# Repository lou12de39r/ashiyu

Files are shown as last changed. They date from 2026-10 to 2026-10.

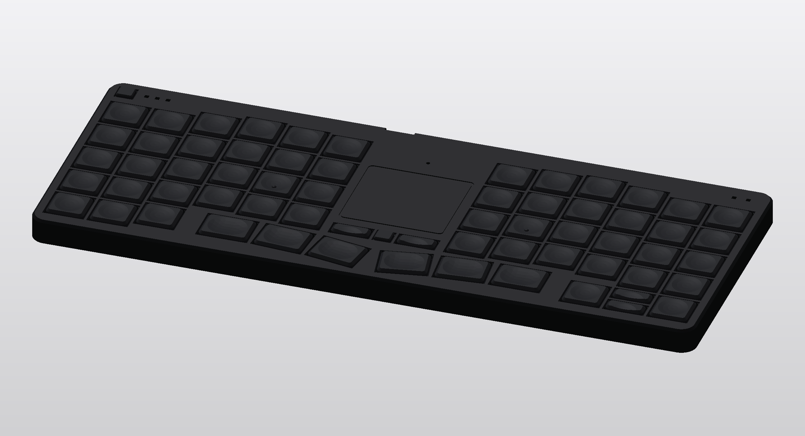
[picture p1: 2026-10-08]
docs/case_black_black_caps.png

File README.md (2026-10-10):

# Ashiyu（足湯）— tomtho-slim mk2: layout v20 and board plan

**Ashiyu（足湯）** — tomtho-slim mk2 の愛称。Designed by tommys079.
Inspired by [ClickBoard](https://salicylic-acid3.hatenablog.com/) by Salicylic_acid3（自作キーボード温泉街）. Keycap models are derived from ACC Keycaps (CC BY-NC 4.0).

This repository holds the frozen layout and the board plan for the second keyboard: roBa-style column stagger, centre trackpad, thin case.

| File | Contents |
|---|---|
| `layout_v20.py` | Script that draws the layout (`roba_ortho_v20.png`) |
| `layout_v20.json` | Fixed coordinates of every key, the trackpad and the LEDs (mm; origin is the rear-left corner of the outline, +y towards the user) |
| `freeze.py` | Regenerates the JSON above from `layout_v20.py` |
| `ORDER.md` | 発注手順: JLCPCB の基板と実装, JLC3DP のケース |
| `case/` | ケース: 上フレームと底板 (CadQuery)。出力は `case-results` ブランチ |
| `layout_v20_print_A4.pdf` / `print11.py` | 1:1 print sheet (A4 landscape). Print at **actual size / 100%** and check the 100 mm bar with a ruler |

## Settled specification

### Layout
- **Keys:** 66 total (v22: lower-left Ctrl 1u, Fn / Win 0.5u stacked, Alt 1u, mirroring the arrow cluster).
  - Left block: 6 columns × number row + 3 rows, plus Fn / Ctrl→**Alt** (firmware) / Win.
  - Right block: 6 columns × number row + 3 rows, plus arrows (← ↑↓ →; ↑ and ↓ are stacked 0.5u keys).
  - Thumbs (v21): 3 per side — outer 1u, **middle (Space / Enter) 1.25u**, inner 1u — at 1.1u spacing. Fan is half of roBa's: tilt 0 / 4.5 / 10°, drop 0 / 0.8 / 3.5 mm.
  - Centre: mouse L / R (1u × 0.5u) and M (0.5u × 0.5u), 2.5 mm below the trackpad window (v21).
  - Rear strip, top-left: BT key (0.5u × 0.5u; tap = next profile, 1 s hold = clear and re-pair).
- **Pitch:** 18.5 × 18.0 mm.
- **Column stagger (v21):** 0.75 × roBa's offsets (was 0.5). Relative to the pinky column: ring 5.0, middle 8.3, index 6.6, inner 4.8 mm towards the rear. The trackpad top lines up with the tops of T / Y; the MCU module, USB-C and charger sit in the free area above it (nothing is stacked under the trackpad).
- **Outline:** 277.0 × 107.5 mm.
- **Trackpad:** Azoteq **TPS43-201A-S** module, 43 × 40 mm (window centred in the 51 mm centre gap, top aligned with T / Y). The keys did not move when the pad shrank from 49 × 42.
- **LEDs:**
  - BT1–3, green: light for 3 s on a press; blink while waiting to pair.
  - Power, yellow-green/red bicolour XL-2012SURSYGC (firmware): green for 3 s on power-up and on a profile switch; below 20 % a short red blink every 5 s.
  - Charge, orange: driven directly by the charger STAT pin; lights only while USB is connected.

### Matrix and GPIO (draft)

| Row | Left side (C0–C5) | Right side (C6–C11) |
|---|---|---|
| R0 | ` 1 2 3 4 5 | 6 7 8 9 0 - |
| R1 | Tab Q W E R T | Y U I O P [ |
| R2 | Ctl A S D F G | H J K L ' ] |
| R3 | ⇧ Z X C V B | N M , . / Ent |
| R4 | Fn Alt Win 変換 Space 無変換 | BS Enter Del ← ↑ → |
| R5 | BT L M R ↓ (5 keys) | — |

**Pin budget:**

| Function | Pins |
|---|---|
| Matrix (6 rows + 12 columns) | 18 |
| BT LEDs | 3 |
| Power LED | 2 |
| Trackpad (SDA, SCL, RDY, RST) | 4 |
| **Total** | **27** |

Charger STAT is **not** wired to the MCU: the MCP73831 drives STAT up to VBUS (5 V) when charging is done, which would overdrive an nRF GPIO. Firmware can see USB power from the nRF's own VBUS detection instead.

The MDBT50Q has room to spare. Reset, NFC and crystal pins are avoided.

### Trackpad (decided: Azoteq TPS43-201A-S module)
- **Module:** IQS572, 43 × 40 mm, PCB 1.0 mm, ships with 3M 468 adhesive (0.13 mm) for sticking to the underside of an overlay. 1.65–3.6 V, I²C. Ordering code: hardware rev 2 = **ZIF connector** (J1) on the module.
- **J1 pinout (datasheet table 2.1):** 1 RDY, 2 NRST, 3 GND, 4 VDDHI, 5 SCL, 6 SDA. The main board's J3 uses the same numbering.
- **Mounting:** stuck under the case-top window; its underside parts hang into a 44 × 41 mm cut-out in the main board, so the pad sits flush with the case top.
- **Cable:** 6-pin FFC from the module's ZIF to J3 (HC-FPC-05-10-6RLTAG, 0.5 mm). **Unchecked:** the module ZIF's pitch, position and contact side. Choose cable type A or B so that pin 1 reaches pin 1 (a mirrored cable swaps GND and VDD).
- **Gestures:** XY for up to 5 fingers; the IQS572 does 1- and 2-finger gestures itself (two-finger scroll). Three-finger swipe = app switch, done in the firmware driver from the touch coordinates (hold Alt, Tab / Shift+Tab per 8–10 mm, release Alt on lift).
- **Supply (2026-10-08):** Mouser 0 in stock, 170 due 10/28/2026, $4.57 each.
- **Alternative:** the GR-Trackpad65-derived IQS550 board in `trackpad/` (49 × 43, hand-soldered IC) is kept, but it no longer fits the 44 × 41 cut-out.

## Schematic (mk2-0.1)

- **Files:** `tomtho_mk2.kicad_sch` (KiCad 9). `gen/build_sch.py` regenerates it from `gen/design.py`, which in turn reads `layout_v20.json`. CI ERC: **0 errors, 0 warnings**. The netlist re-extracted from the schematic matches `design.py`.
- **Matrix:** drawn as a wired grid, COL → SW → D → ROW.
- **Charge LED:** red KT-0603R, driven straight from the charger STAT pin.
- **Footprints:** USB-C, bicolour LED and FPC come from the LCSC/EasyEDA data (`gen/lcsc/`). Bicolour LED pins: 1 = R−, 2 = R+, 3 = YG−, 4 = YG+.

## PCB (mk2-0.1)

- **Board:** `tomtho_mk2.kicad_pcb`, 2 layers, 276 × 107 mm.
- **Build pipeline:**
  1. `gen/route.py` writes a Specctra DSN and runs Freerouting. GND is routed as a normal net (a tree), then poured on both layers.
  2. `gen/post.py` adds about 600 GND stitching vias.
  3. `gen/build_pcb.py` writes the board, fills the zones and runs KiCad DRC.
- **Check:** DRC with schematic parity gives **0 violations, 0 unconnected, 0 parity** in both local KiCad 10 and CI KiCad 9.
- **Fab files:** JLC BOM/CPL are in `jlc/`. CI exports the Gerbers and drill files to `ci-results:gerber`.
- **USB-C:** top-mount HRO TYPE-C-31-M-12 (C165948). It sits in the free area, so the mid-mount part is not needed.
- **Trackpad cut-out:** 44 × 41 mm for the TPS43, J3 and the I²C pull-ups to its left.
- **ACC keycaps:** their four corner legs come down to 1.5 mm above the PCB (0.5 mm when pressed). The ↑ / ↓ diodes and J3 were moved clear of these leg zones (r 2 mm at the corners minus 1.7 mm).
- **Case mounting (no screws):** 9 × Tadpole Pin D3.0 holes (H1–H9, NPTH Ø 3.1): 4 rear, 2 front, 3 centre (both sides below the trackpad and between the inner thumbs). The case is screwless (hidden spring clips).
- **References:** reset switch SW101, power switch SW102, Schottky D101 (SW1–SW66 / D1–D66 are the keys).
- **JLC placement (CPL):**
  - `gen/jlcrot.py` lays each LCSC/EasyEDA footprint (the one JLC places at 0°) over ours and works out the rotation offset and origin shift. `jlc/*_CPL.csv` already includes them, in the Gerber coordinates (+Y up, as `kicad-cli pcb export pos`).
  - Verified: with the CPL as written, every LCSC pad lands on our pad (≤ 0.2 mm) for every part, including the tilted thumb keys.
  - Offsets applied: SOT-23 +180°; SOT-23-5 / SOT-23-6 +270°; USB-C origin 1.57 mm; MDBT50Q origin 1.70 mm.
  - Checked by pin function rather than pad number: the KT-0603R LED (LCSC pad 2 = K) and the SKRA / TS-1928-B switches (joined pairs 1-2 / 3-4).
  - Still look at JLC's preview once before paying.
- **Charge current:** R3 = 4.7 kΩ → about 210 mA (0.2–0.5 C for an 800–1000 mAh cell; use ≥ 420 mAh).
- **Before ordering, check:**
  - **MDBT50Q-1MV2 (C5118826) stock: LCSC showed 0 (2026-10-08).** If JLC has none either, use pre-order / global sourcing, or send the modules in yourself.
  - **Battery polarity:** J2 pin 1 = + (VBAT). LiPo leads with JST SH plugs come both ways round; check with a meter before plugging in (reversed = charger and MCU destroyed).
  - Board thickness **1.2 mm** must be chosen in the order form.
  - The routing is automatic and rough in places; it could be tidied by hand.
- **Firmware must:**
  - Set UICR REGOUT0 to 3.0 V. The module runs from VDDH, and the erased default is 1.8 V, at which the LEDs (Vf ≈ 1.9–2.0 V) stay dark.
  - Enable pin reset on P0.18.
  - Drive the LEDs active-low (cathode to GPIO).

## Parts check (2026-10-07, LCSC / JLCPCB pages)

| Part | Result |
|---|---|
| IQS550BLQNR (C5271144) | **Out of stock at LCSC.** The trackpad board cannot be assembled at JLC as planned |
| USB-C TYPE-C 16PIN 2MD(073) (C2765186) | In stock, but right-angle SMD, not mid-mount. Not used |
| **USB-C SHOU HAN TYPE-C 16P CB1.6 073 (C2906290)** | **Use this.** Mid-mount (sinks 1.6 mm), 16-pin, 6.5 mm long, plentiful stock (LCSC). JLC rates assembly difficulty "High". It is made for a 1.6 mm board, so on our 1.2 mm board it sticks out about 0.4 mm below → add a pocket in the case bottom |
| FPC 0.5 mm 6-pin HC-FPC-05-10-6RLTAG (C5213729) | In stock (5k), bottom contact, flip lock |
| Green LED 19-217/GHC (C72043) | Vf 3.3 V: **too high for a 3.0 V VDD**. Needs a yellow-green (≈2.0 V) part instead |
| Red LED KT-0603R (C2286) | Vf 1.8–2.4 V, usable |
| Bicolour LED XINGLIGHT XL-2012SURSYGC (C965847) | **Use this.** 2.0 × 1.2 mm, common anode, red + yellow-green (Vf ≈ 2.4 V at 20 mA; lower at 1–2 mA, so it works from 3.0 V). In stock (20k) |
| IQS550-BL-QNR elsewhere | Octopart lists it only at non-authorised resellers (about 1.1k and 32k pcs, $1.7–3.0). Stock at Mouser / DigiKey could not be read (unconfirmed) |

## Verify before ordering (in priority order)
1. **TPS43 connector:** get the drawing (or measure a module): the ZIF's pitch, position and contact side, and the FFC length and type. Pin 1 must reach pin 1.
2. **ZMK driver for the IQS572 / TPS43:** QMK has an Azoteq IQS5xx driver. For ZMK only community drivers exist (unchecked).
3. **Height:** check that the parts in the free area (module about 2.2 mm, USB-C) fit under the case top, and that the TPS43's underside parts clear the cut-out and the case floor.
4. **Keycaps:** fit of the Acid Caps on the tilted thumb keys, checked by laying out the 3D data.
5. **0.5u × 0.5u caps (BT, M):** these are not sold, so they must be made. Print a test piece first.

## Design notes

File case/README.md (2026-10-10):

# Ashiyu (tomtho-slim mk2) case: top frame + bottom plate

The case is generated in CadQuery by CI (`.github/workflows/case.yml`). Results, including STEP/STL files, section views and interference checks, go to the **`case-results`** branch.

## Files

| File | Role |
|---|---|
| `export_inputs.py` | Run locally with KiCad's python. Reads the finished PCB and layout and writes `case_inputs.json`. |
| `build_case.py` | CI. Builds the top frame, bottom plate and 0.5u × 0.5u keycap, and exports STEP + STL. `KEY_CLR` adds extra keycap-hole clearance per side. |
| `check_case.py` | CI. Checks keycaps (at rest and pressed 1 mm) against the frame, the bottom plate and part blocks, and draws section PNGs. |
| `measure2.py`, `measure_ref.py` | CI. Measure the reference STEP files (ACC keycaps, ClickBoard Tenkey case, LCSC part models). |
| `render_stl.py` | Local shaded STL preview (numpy + matplotlib). |

## Build heights

z = 0 is the case bottom.

| Level | z (mm) | Notes |
|---|---|---|
| Bottom plate floor | 0 – 1.0 | |
| LiPo pocket | 1.0 – 4.3 | ≤ 3.0 × 40 × 70 cell |
| PCB bottom (seam between the two parts) | 4.3 | |
| PCB top | 5.5 | |
| Plate | 8.5 – 10.5 | 2.0 mm thick. Starts 3.0 mm above the PCB; ACC hooks catch under it, as in the ClickBoard Tenkey case. |
| Keycap top | 11.5 | thumb caps 11.8 (domed, raised 0.3) |

Outline: 283.0 × 114.5 mm. Plan corners R10 front / R8 rear (ClickBoard Tenkey: R10), top chamfer 3.0, bottom chamfer 1.5 (as the Tenkey STEP). Walls from the PCB edge: 3.6 sides and rear, 4.6 front, so every keycap hole keeps ≥ 2.4 mm to the flat top face, corners included. Fingernail relief round the power switch.

## Keycaps

- **ACC (Acid Caps ClickProfile, Salicylic-acid3):**
  - 1u × 51, plus 1u Home × 2 (F, J).
  - 0.5u, i.e. 1u × 0.5u, × 4 (L, R, ↑, ↓).
  - Thumb keys (1u × 4, 1.25u × 2) use printed domed caps instead (see below).
- **Plate holes:** keycap body + 0.14 mm per side, as in the ClickBoard Tenkey case.
  - 1u: 16.5 × 16.0.
  - 1.25u: 21.0 × 16.0.
  - 1u × 0.5u: 16.5 × 7.0.
  - 0.5 mm 45° lead-in at the top.
- **BT and M (0.5u × 0.5u):** no ACC part exists, and hooks cannot fit because the SKRA body (6.2 square, 2.8 mm tall) fills the hole.
  - Uses the printed flange cap `tomtho_mk2_keycap_0.5u_x_0.5u`.
  - The plate is thinned to 0.8 mm around these keys.
  - The cap goes into the frame **from below, before the PCB**.

## Other features

- **TPS43 trackpad (no cover plate):** the module goes in **from below** (before the PCB) and is touched directly through a 41 x 38 mm window (r2, 0.3 chamfer); a 1.0 mm wide, 0.5 mm thick lip holds its edge, so the sensor face sits 0.5 mm below the top. The module's own 3M 468 tape sticks it to the lip; a PORON block (about 4 mm) on the tray's cross ribs presses it up.
- **LEDs:** 1.8 mm windows, with light shrouds that stop 1.0 mm above the PCB.
- **Reset:** a printed plunger in a 4.8 mm hole over the reset switch (no pin needed). Its stem is 3.0 mm across, covering the whole switch top, so slight offset or tilt still presses it; the stem ends 0.1 mm above the switch. It goes in from below like the 0.5u caps; two plungers are on the 0.5u keycap sprue.
- **Rear wall:**
  - USB-C notch (open at the top: a 6 mm plug overmold leaves no wall above it).
  - Power-switch slot.
- **No screws:** the top frame's skirt runs down to the desk; the bottom tray fits inside it and clicks in with 8 hidden spring clips. The PCB floats on 9 Tadpole Pin D3.0 (50A): Ø 3.0 blind holes in Ø 5.2 bosses of the top frame, Ø 4.8 cups in the tray. Top edge: 1.5 mm 45° chamfer, no ring.
  - Plate posts (1.4 square) in the webs between keys keep the plate height.
- **Rubber feet:** 8 recesses (d6.6 x 0.5 mm) under switch islands for d6 mm pads: 4 front (1.5 mm), 4 rear (3.0 mm) -> about 1.2 deg tilt.
- **Bottom plate:** 7 × 7 support islands under every switch (none over the LiPo), solid blocks under USB-C, the power switch and reset, and counterbores for the screw heads.

## Reference data

Measured only, not copied: the ACC keycaps (`Salicylic-acid3/ACC_Keycaps`) and the ClickBoard Tenkey case (`Salicylic-acid3/Case_Data`) are both CC BY-NC 4.0. CI clones them at build time; this repo stores only numbers derived from them.

## Keycap files (`keycaps.py`, CI → `case-results:keycaps/`)
- **One file per size** (STEP + STL): 1u, 1u home (F / J), 1.25u, 1u × 0.5u, and 0.5u × 0.5u (our flange cap).
- **Mouse buttons L / R:** 1u x 0.5u ACC caps with the dish filled flat (`keycap_1u_x_0.5u_flat`).
- **Up mark:** every printed cap has a filled triangle engraved on its underside, pointing to the rear of the board.
- **Thumb caps** `keycap_1u_thumb` / `keycap_1.25u_thumb`: the ACC cap with the dish (about 0.45 mm deep) filled and a gentle ellipsoid dome on top.
  - The top is raised 0.3 mm, so the dome's edges sit near the other caps' rim height. The peak is 0.3 mm above the other keys (11.8 mm total at the thumb row); the middle of each top edge is 0.4 mm below the peak and the corners about 0.75 mm below.
  - Walls, hooks, nub and edge rounding are unchanged ACC. No ACC part exists for these, so they are always printed.
  - The first four are Salicylic-acid3's ACC models, re-centred and converted, under **CC BY-NC 4.0** (see `LICENSE.txt` there).
  - **Non-commercial use only.**
- **Print sprues**: the caps mk2 needs, joined by 1 mm bars at the middle of each side, clear of the corner hooks.

| Sprue | Contents |
|---|---|
| `print_sprue_1u_x29_a`, `print_sprue_1u_x28_b` | 51 needed + 10 % spares (57, split in two so each STL stays under 30 MB) |
| `print_sprue_thumb_1.25u_x3_1u_x6` | thumb caps: 1.25u 2 + 1 spare, 1u 4 + 2 spares (**always printed**) |
| `print_sprue_1u_x_0.5u_x5` | 4 + 1 spare |
| `print_sprue_1u_home_x3` | 2 + 1 spare |
| 0.5u × 0.5u | 6 on the case sprue, with the 2 reset plungers |

- **Printing caution:** the ClickBoard author found that about 1 in 10 caps from a JLC 3D-print trial failed on small burrs. The released ACC caps are injection-moulded PBT. Printed hooks in brittle resin may also snap.

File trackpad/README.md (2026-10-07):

# tomtho-slim mk2 trackpad (49 × 43 mm, IQS550, 10 Tx × 10 Rx)

This board is derived from **GR-Trackpad65** by geek-rabb1t (MIT License, see `LICENSE_GR-Trackpad65`; original files in `src_grt65/`).

GR-Trackpad65 is 65 × 49 mm with 15 Tx × 10 Rx. Its electrode pitch is 4.2 mm (Tx) × 4.7 mm (Rx). Keeping 10 Tx columns gives exactly 42 mm, so **the electrode shape, pitch and IC surroundings are reused as they are**. Only the board was cut down.

## Changes from the original
1. **Cut down to Tx5–Tx14.** Tx0–Tx4 and the PCBA rails are removed. With the 0.6 mm frame, the board is **49.1 × 43.1 mm**, 4 layers, 1.6 mm thick (same as the original).
   - The case window is 49 × 42 mm. The extra 1.1 mm sits under the case top, towards the L/R buttons.
2. **Rx series resistors R9–R12 moved.** They were on the part that was cut off. Rx6–Rx9 were re-routed on B.Cu (Freerouting with a custom single-layer DSN). Rx7–Rx9 also got new vias onto their F.Cu Rx lines.
3. **Rotated 90°** so the board fits the layout (49 wide × 43 tall). The FFC connector J1 is on the back, at +9.43 / +18.09 mm from the top-left corner, with its opening facing −x.
4. **KiCad 10 DRC: 0 errors, 0 unconnected.**
   - Remaining warnings: footprint-library differences, and silkscreen near the board edge.

## Not done / needs checking (in priority order)
1. **IQS550 settings.** A freshly mounted IQS550 does not work as a trackpad.
   - The original's hex file is written for 15 Tx, so it **cannot be used as-is**.
   - Settings needed:
     - Total Tx = 10.
     - Tx mapping = IC pins Tx5–Tx14.
     - Rx mapping is unchanged.
     - Resolution, and so on.
   - Two ways to write them:
     - (a) Write and save them with Azoteq's CT210A programmer and the IQS5xx-B000 GUI.
     - (b) Write them over I2C at every boot from the ZMK driver. **(b) is planned.** No extra tool is needed, but whether every register is writable at run time still has to be checked against the datasheet (uncertain).
2. **The QFN pads were not lengthened.**
   - Lengthening them shorts them to the dense original fan-out traces.
   - Hand soldering assumes **solder paste + hotplate or hot air**. The pads are the standard KiCad QFN-48 7×7 footprint.
   - JLC assembles everything except U1. The CPL/BOM leave U1 out.
3. **Overlay.** The original recommends **2 mm matte acrylic**. Other materials need different settings.
4. **Thickness and mounting.** The trackpad sits in a **cut-out in the main board** and rests on the case floor:
   - case floor 0.5 + clearance for the back-side parts (FFC connector about 2 mm)
   - \+ PCB 1.6 + overlay 2.0
   - ≈ the case top.
5. **FFC.**
   - Cable: 6-pin, 0.5 mm pitch, length about 15 mm, **contacts on opposite sides (type B)**.
   - Main board J3 is arranged so each pad faces the same signal at the same height.
   - Check continuity before fitting.

## Files
| File | Contents |
|---|---|
| `tomtho_mk2_trackpad.kicad_pcb` | Finished board |
| `jlc/*_BOM.csv`, `*_CPL.csv` | For JLC PCBA, assembled on the back side, U1 left out |
| `gen/crop.py` → `gen/route_b.py` → `gen/trim.py` → `gen/finish.py` | Build steps (KiCad Python + Freerouting) |
| `src_grt65/` | Original GR-Trackpad65 data (MIT) |

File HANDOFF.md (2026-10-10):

# Ashiyu（足湯）申し送りメモ（2026-10-11 時点）

## 1. これまでの経緯・目的
- 2作目の自作キーボード **Ashiyu（足湯）** を設計中（1作目は For Glad／tomtho）。サリチル酸さん（Salicylic_acid3）の **ClickBoard** にインスパイアされた、薄型・無線・中央トラックパッド付き・ZMK のキーボード。
- **最終ゴール：発注**
  - 基板と部品実装は JLCPCB の Standard PCBA に出す。
  - ケースとキーキャップは JLC3DP の SLA ブラックレジンで出す。
- **データの場所**
  - リポジトリ：github.com/lou12de39r/ashiyu（KiCad のファイル名は旧名の `tomtho_mk2.*` のまま）。
  - CI の結果は次のブランチに出る。
    - `ci-results`：ガーバー、DRC、BOM、CPL
    - `case-results`：ケースとキーキャップの STL／STEP
- **発注手順書**
  - リポジトリの `ORDER.md`
  - Claude Doc「Ashiyu（足湯）発注手順（JLCPCB／JLC3DP）」：https://claude.ai/code/artifact/c46f96b1-e12b-4dd0-84ab-aebee1806d07

## 2. 決定事項
- **キー配列（v22、66キー）**
  - roBa のずらしを0.75倍にした配置。ピッチは 18.5×18.0。
  - 親指キーは 1u／1.25u／1u。
  - 中央に TPS43 トラックパッド（43×40）。その下に L／M／R キー（L・R はくぼみ無し）。
  - 右下は矢印キー：← 1u、↑↓ 0.5u の上下2段、→ 1u。
  - **左下は Ctrl 1u、Fn／Win 0.5u の上下2段、Alt 1u**（右下の矢印キーと左右対称）。
- **キーマップ**は tomtho の default がベース。テンキーは中央に置き、右手で打つ。
  - ⚠️ **パスワードのマクロ（MC_PASS）は絶対に移植しない。** 元の公開リポジトリのパスワードは変更を勧めてある。
- **スイッチ**：ALPS SKRAAWE010（C202383）のまま。
  - Kailh のマイクロミュートスイッチは高さ 7.3 mm で、ケースが約4 mm厚くなるため不採用。
- **MCU**：MDBT50Q-1MV2（C5118826）。在庫切れのため、取り寄せはせずに入荷を待つ。
- **基板**：2層、厚さ 1.2 mm。背面のシルクに次を入れる。
  - 「Ashiyu」
  - 「Designed by tommys079」
  - 「Inspired by ClickBoard」
  - tommys079 のロゴ
  - JLC の注文番号の位置は、電池の下（目立たない場所）に移動済み。
- **ケース**
  - 素材は SLA ブラックレジン。仕上げの「General Sanding」は「いいえ」を選ぶ（フックを守るため）。
  - **ネジなし**。上フレームの外壁が机まで下り、底板は内側にはまる。隠し爪は8か所。
  - 天面の面取りは **3.0 mm**、底の面取りは **1.5 mm**（ClickBoard Tenkey の STEP 実測値と同じ）。リングは無し。
  - 角は**手前が R10、奥が R8**。奥の左角には BT キーがあり、R10 にすると奥の壁を 5.6 mm にする必要が出るため。
  - 壁の厚さ（基板の縁から外まで）：左右と奥は 3.6 mm、手前は 4.6 mm。全キー穴が、平らな天面の縁から 2.4 mm 以上離れる（角も直線部と同じ）。
  - 外形は **283.0×114.5 mm**（コミット 8b87b86、干渉0）。電源スイッチのまわりに、爪を掛けるくぼみがある。
  - 基板は **Tadpole Pin D3.0（50A）×9本** の上に浮かせ、外からは見えない。手持ちは10本なので1本は予備。
- **トラックパッド**：**カバー板は無し**。TPS43 の表面を直接触る。
  - 上フレームの窓は 41×38。ふち（1.0 mm 幅、0.5 mm 厚）で下から押さえる。
  - TPS43 の下に PORON を約 4 mm 入れる。
- **キーキャップ**：ACC（ClickProfile）をもとにした印刷品。データは CC BY-NC なので個人利用のみ。
  - 親指キーはふっくら型で、少し持ち上げてある。
  - 0.5u×0.5u キーはフランジ式で、角は丸い。
  - 全キャップの裏に、上向きを示す三角印を入れてある。
- **その他の部品**
  - 底面の PORON は 3 mm。
  - ゴム足は YAHATA Slim Flex のハード。手前に 1.5 mm を4個、奥に 3 mm を4個（約1.2° 傾く）。
  - リセットボタンは指で押せるプランジャー式。

## 3. 未解決・進行中のタスク
- ✅ 完了（2026-10-11、コミット 7a649e5 以降）：v22 の基板を再配線（Freerouting 1.9）。CI の DRC は違反0・未接続0・回路図との不一致0。ケースの干渉チェックも0。
  - 発注データ一式（JLC3DP の STL 8個、JLCPCB のガーバー・BOM・CPL）は作成済み。
  - 部品の参照番号を変更：リセット SW101、電源 SW102、ショットキー D101（SW1〜66／D1〜66 はキー）。
1. **Claude Doc の発注手順書を v22 の内容に更新する**（ORDER.md は更新済み）。主な変更点は次の4つ。
   - ネジ無し、Tadpole 9本。
   - トラックパッドのカバー板を廃止。
   - キーキャップの数：1u 50＋予備5、1u×0.5u 4＋1、くぼみ無し 2＋1。
   - 基板の参照番号の変更。
2. **トラックパッドの大きさを決める**：TPS43（43×40、窓 41×38）のままにするか、TPS65（65×49、IQS550、Mouser に在庫あり）にするか。横置きにすると横幅が約15 mm 増える。縦置きなら横幅は変わらないが、電子部品の移動と、奥行きが約20 mm 増える。どちらにしても、基板の中央部分を配置し直して配線し直す必要がある。
3. ORDER.md に追記する：SWD での初回ブートローダー書き込み（TP1〜4）。
3. **保留・要確認**
   - TPS43 の裏の部品の高さ：PORON の厚さを決めるのに必要。
   - TPS43 側の ZIF コネクタの向きと、FFC の種類：TPS43 が届いてから実測する。Mouser は10/28入荷予定。
   - 電池の極性：J2 の1番ピンが＋。挿す前にテスターで確認する。
   - ファーム（ZMK）とキーマップの作成：未着手。

## 4. Claude の役割・トーン（ユーザー設定）
- 各分野のプロとして100点の回答をする。結論から簡潔に、そのあと理由・具体例・次の行動を示す。
- 「自分ならどうするか」という意見も言う。
- 情報が足りないときは、チェックボックス式の選択肢で質問する。
- 問題を構造的に分解し、優先順位・所要時間・手順を示す。
- 上司や第三者の目で厳しくチェックする。弱い点、盲点、リスク、代替案を比べて示す。
- 正直に書き分ける。
  - 分からないことは「わからない」と言う。
  - 自信がない部分は「不確か」と明記する。
  - 情報が古い可能性があれば伝える。
  - 裏を取るべき箇所と、逆の結論になる可能性も書く。
- 家族構成：妻、長男（令和5年生まれ）、二男（令和7年生まれ）。
- やり取りはスマホが中心で、日本語。頼まれていない設計変更は勝手にコミットしない（過去に1度あり、元に戻した）。

## 5. 次のチャットの冒頭の一言
「Ashiyu（足湯）の続きですね。申し送りを確認しました。v22（左下 Ctrl・Fn/Win・Alt、Tadpole 9本、カバー板なしのトラックパッド）は、基板の DRC もケースの干渉チェックも0で、発注データもそろっています。残りは Claude Doc の手順書の更新と、TPS43 が届いてからの実測です。手順書の更新から進めましょうか？」

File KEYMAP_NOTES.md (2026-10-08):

# mk2 キーマップ要件（ファーム作成時に反映する）

**元にするキーマップ**：lou12de39r/qmk-tomtho の `keymaps/default/keymap.c`。これを ZMK に移植する。

## default キーマップの要点（tomtho）

**ベース層**
- 中央に常に使えるテンキー（7 8 9 ／ 4 5 6 ／ 1 2 3）
- 右下に矢印キー（↑、← ↓ →）
- 一部のキーは「押す」と「押し続ける」で役割が変わる：

| キー | 押したとき | 押し続けたとき |
|---|---|---|
| Tab | Tab | Ctrl |
| J | J | Ctrl |
| / | / | Shift |
| 無変換（INT4） | 無変換 | Alt |
| Caps | Caps | 4番層 |
| Space | Space | 2番層 |
| 0 | 0 | 3番層 |
| Enter | Enter | 1番層 |
| F | F | 5番層 |

- タップダンス（押す回数で役割が変わる）
  - Q：1回で Q、2回で Win+Tab、押し続けると Alt+F4
  - Win：1回で Win、2回で Win+D
- コンボ（同時押し）

| 同時押し | 出るもの |
|---|---|
| ↓ と → | Del |
| , と ↑ | . |
| J K L | Win+Shift+S（スクリーンショット） |
| J K | 「()」を入力 |
| L と - | _ |
| 9 と Y | : |
| 6 と H | ; |
| Z X ／ X C ／ C V | 切り取り ／ コピー ／ 貼り付け |
| D F | F2 |
| S D F | Shift+F10 |

**各層の中身**
- **1番層（Enter 長押し）**：記号
  - 中央のテンキー位置：シフト付きの数字
  - 左手 A S D F：/ * - +
  - 右手：@ ^ _ : ; ＼（INT1）など
- **2番層（Space 長押し）**：**右手の U I O ／ J K L ／ M , . がテンキー**になる
  - 最下段に 0 . , /
  - 右端に + - *
  - 左手に Home／End／PgUp／PgDn、Ctrl+Home／End、Ctrl+A／Z／X／C／V
  - 中央に F1〜F12
- **3番層（0 長押し）**：マウス操作
  - 左手 E S D F でカーソル移動
  - ホイールとクリック、Ctrl+Tab／Ctrl+Shift+Tab
- **4番層（Caps 長押し）**：ブートローダー起動・再起動、F1〜F12、マクロ（文字列の自動入力）、PgUp／Home／PgDn／End
- **5番層（F 長押し）**：左手のキーを Ctrl+キーに（W E R、A S D F G、Z X C V B）
- **6番層**：Win+数字、Excel 用マクロ。ベースから入るキーが無いので、移植するかは要確認

## mk2 での要件
- **テンキー**：2番層（Space 長押し）の右手テンキーを、そのまま mk2 の U I O ／ J K L ／ M , . に移す。今と同じ感覚で使える。
  - 中央の常時テンキーは、トラックパッドに置き換わるので無くなる。
  - 数字をまとめて打つ場面用に、2番層をトグル（押すたびに ON/OFF）できるキーも用意する。ON の間は電源 LED を緑で点けておく。
- **矢印**：右下の矢印はそのまま置く。**左手側にも矢印**を追加する（E／S／D／F → ↑ ← ↓ →）。
  - 3番層の左手はマウス移動になっているので、矢印をどの層に置くかはファーム作成時に決める。
- **マウス**：3番層のマウス操作は、トラックパッドと L／R／M キーがあるので、何を残すかを見直す。
- **0 キー**：tomtho は親指の 0 が 3番層キーを兼ねている。mk2 の親指キーへの割り当ては、ファーム作成時に決める。
- **マクロの移植（重要）**：パスワードなどの秘密情報は、**キーマップに書かない**。

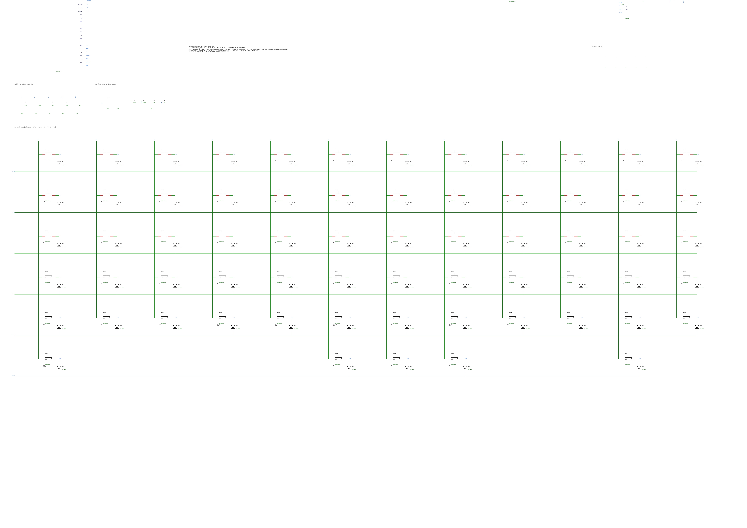
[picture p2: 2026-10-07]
docs/schematic_matrix.png

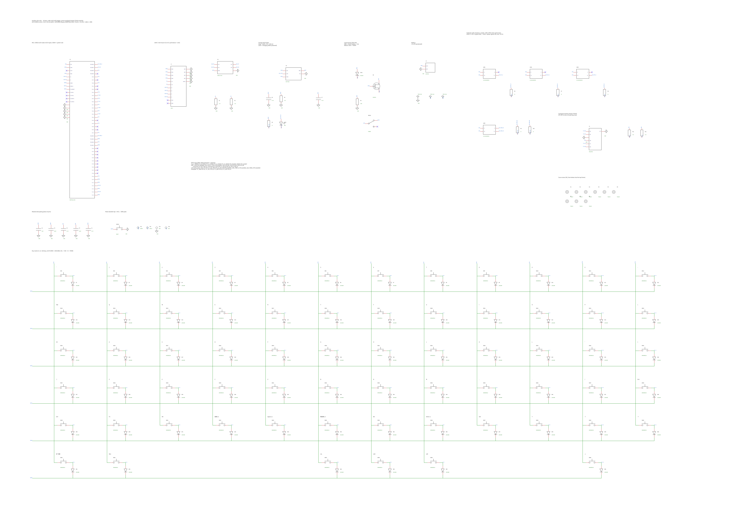
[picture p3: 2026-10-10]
docs/schematic_full.png

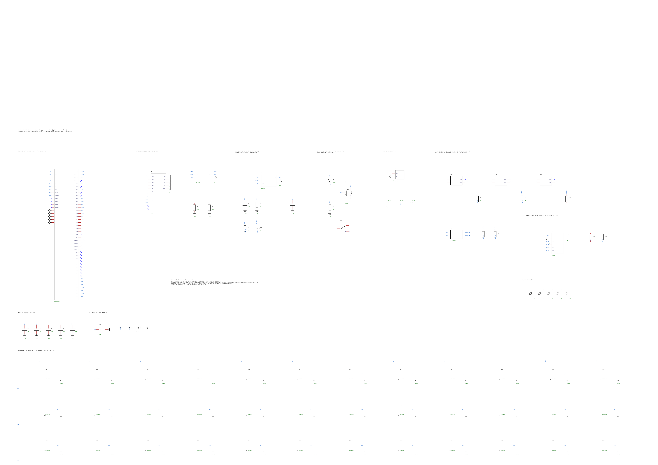
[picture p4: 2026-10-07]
docs/schematic_power.png

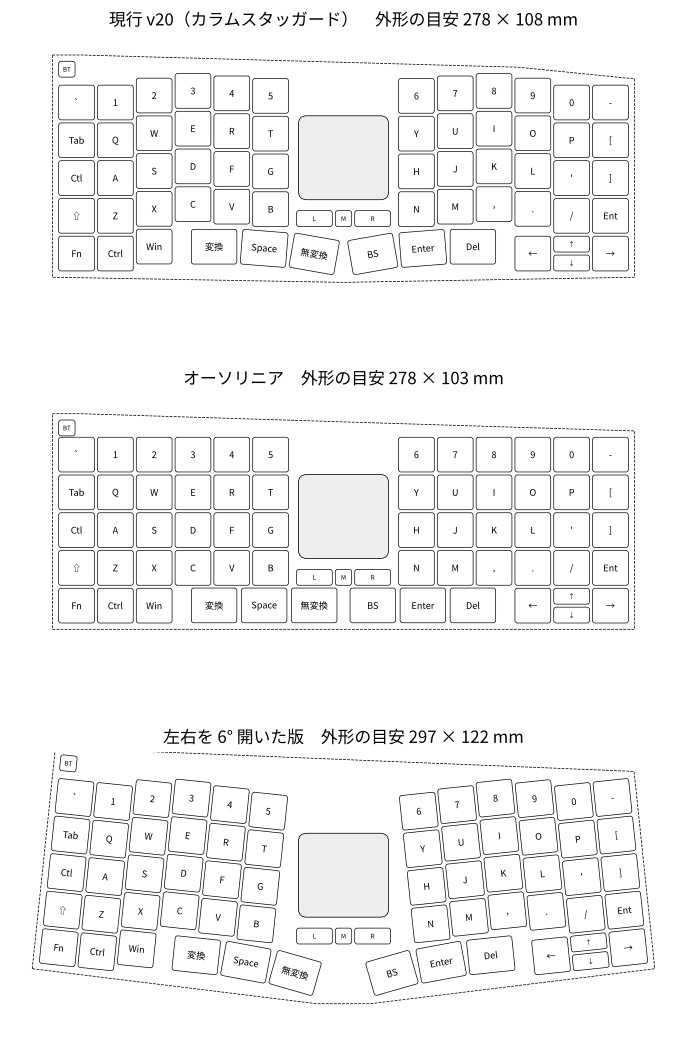
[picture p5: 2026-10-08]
docs/layout_compare3.png

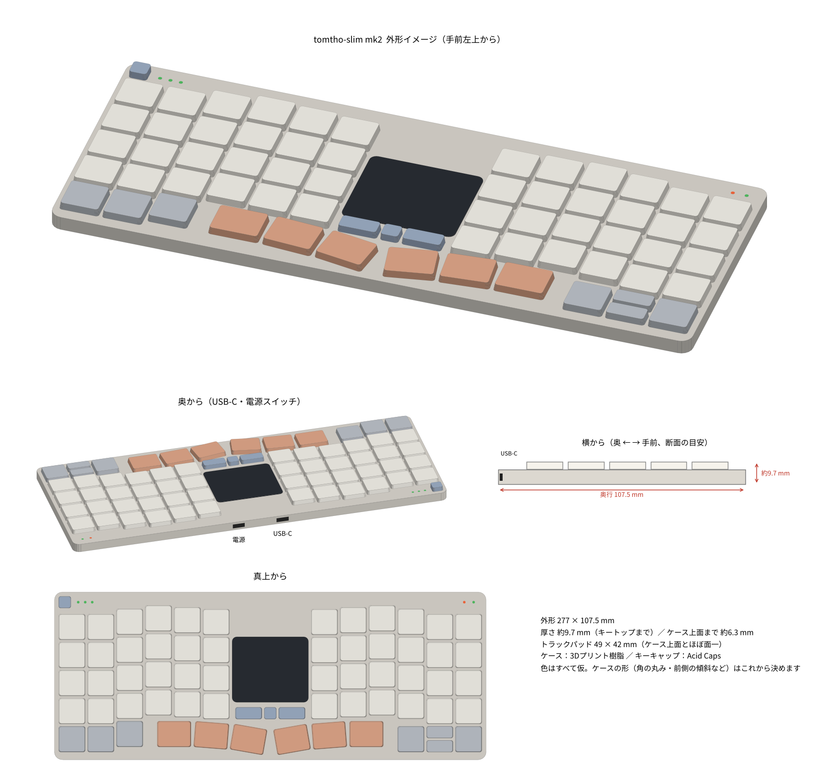
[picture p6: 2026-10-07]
docs/exterior_v20.png

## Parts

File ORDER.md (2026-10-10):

# Ashiyu（足湯）発注手順（JLCPCB 基板＋実装 / JLC3DP ケース）

## 0. 先に確認すること（ここが崩れると発注をやり直すことになる）
- [ ] **MDBT50Q-1MV2（C5118826）の在庫**：JLCの部品ページで確認する。在庫が無い場合は、JLCの予約注文（pre-order／グローバル調達）を使うか、自分で買ってJLCに送る（持ち込み）。
- [ ] **TPS43-201A-S の入手時期**：Mouserでは10/28入荷予定。届いたら次の2点を実測する。
  - コネクタ（ZIF）の位置・ピッチ・接点が上下どちら向きか。
  - それに合うFFCの長さと種類（同じ面か反対面か）。
- [ ] **電池**：厚さ3.0 mm以下、40×70 mm以内、1セルのLiPoで、JST SH 2ピン（1.0 mmピッチ）のもの。**基板側（J2）の1番ピンが＋なので、挿す前にテスターで極性を確認する。**

## 1. JLCPCB：基板と部品実装
| 項目 | 設定 |
|---|---|
| ガーバーデータ | `ci-results` ブランチの `gerber/` をzipにまとめてアップロード |
| 層数 | 2 |
| 外形 | 約 275.8 × 106.3 mm（アップロードすると自動で読み取られる） |
| **基板厚** | **1.2 mm**（初期値の1.6のままにしないこと） |
| 表面処理 | HASL（鉛フリー）またはENIG |
| 実装（PCBA） | **Standard**、表面のみ（MDBT50Q がX線検査必須の「Standard Only」部品のため Economic は不可） |
| 部品表（BOM） | `jlc/tomtho_mk2_BOM.csv` |
| 部品配置（CPL） | `jlc/tomtho_mk2_CPL.csv`（座標と向きの補正は済んでいる） |

**部品配置プレビューで目視確認すること**
- 斜めに配置した親指キー6個のスイッチが、パッドに乗っているか。
- USB-C、MCUモジュール、LED（極性）、ダイオード（帯の向き）、SOT-23系部品の向き。

## 2. JLC3DP：ケース
ファイルは `case-results` ブランチにある。

| 部品 | ファイル | 個数 |
|---|---|---|
| 上フレーム | `case/tomtho_mk2_top_frame.stl`（または .step） | 1 |
| 底板 | `case/tomtho_mk2_bottom_plate.stl` | 1 |
| 親指キー（ふっくら型）1.25u×3 ＋ 1u×6 の連結品 | `keycaps/print_sprue_thumb_1.25u_x3_1u_x6.stl` | 1（1.25u は2個使って1個予備、1u は4個使って2個予備） |
| 0.5u×0.5u キーキャップ（BT・M）×6 ＋ リセットボタン×2 の連結品 | `case/tomtho_mk2_keycap_0.5u_x6_reset_x2_sprue.stl` | 1（キャップ6個が細い棒でつながった1部品。キャップ1個だけでは JLC3DP の最小サイズを下回るため。届いたらニッパーで切り離してやすりで整える。2個使って4個は予備。リセットボタンは1個使って1個は予備） |

**素材：SLA レジン（決定）**
- 使うファイル：`case/`（キー穴の隙間は片側0.14 mm。ClickBoard Tenkey と同じ値）
- 色・種類の候補：黒系なら JLC Black Resin / Imagine Black Resin / Black Resin、白なら 9600 Resin（いちばん安い）
  - JLC3DP の素材一覧のページには、各レジンの強さ（割れにくさ）や耐熱温度が載っていない（不確か）。各素材の詳細ページで確認する。
- 精度（設計ガイドの値）：100 mm までは ±0.2 mm、100 mm を超えると ±0.3%
  - 全長 280 mm では最大 ±0.8 mm ずれる可能性がある。キー穴の位置がずれる方向に効く。
- **レジンの注意点**
  - 硬いが割れやすい。底板の爪は、初回は特にゆっくりはめる・外す。
  - 熱に弱い。夏の車内など高温の場所に置かない（変形するおそれがある）。
  - 大きく平らな部品なので、反りが出るおそれがある。届いたら、平らな机に置いてがたつきを確認する。
- **ネジは使わない**：上フレームの外壁が机まで下りていて、底板はその内側に下からはまり、隠れた爪8か所（前4・後2・左右各1）で留まる。横から見ると継ぎ目は見えず、底面に細い線が出るだけ。
- 基板は **Tadpole Pin D3.0（50A）×9本** の上に浮かせて支える（外からは見えない）。上フレームの柱に φ3.0 の止まり穴、底板に φ4.8 の受け、基板の穴は φ3.1。
- MJF ナイロン用の `case_mjf/`（キー穴を広げた版）は、今回は使わない。

## 3. 用意する部品
- **Tadpole Pin D3.0（50A）：** 9本使う（手持ち10本で1本予備）。棒の先が長い場合は、カッターで約1 mm切って長さを合わせる（GEONWORKSの図は1.5 mmプレート基準、こちらは1.2 mm基板のため）。
- **キーキャップ：** 全部 JLC3DP で印刷する場合は、下の連結品を追加で発注する（ACC のデータは CC BY-NC：個人利用のみ）。
  | 連結品 | 使う数＋予備 |
  |---|---|
  | `keycaps/print_sprue_1u_x28_a.stl` と `keycaps/print_sprue_1u_x27_b.stl`（2部品に分割。左下の Ctrl・Alt を含む） | 50＋5 |
  | `keycaps/print_sprue_1u_home_x3.stl`（F・J） | 2＋1 |
  | `keycaps/print_sprue_1u_x_0.5u_x5_flat_x3.stl`（↑・↓・Fn・Win 用5個、L・R 用くぼみ無し3個） | 4＋1、2＋1 |
  - 公式の ACC（PBT）を買う場合は 1u×50、1u Home×2、0.5u（1u×0.5u）×6（L・R をくぼみ無しにするなら印刷品を使う）。親指の6キーはふっくら型を印刷するので、どちらの場合も買わなくてよい。
  - おすすめ：先にケースと小さい連結品だけ発注し、フックがプレートに掛かるか確かめてから 1u の連結品を発注する。
- **FFC：** 6ピン・0.5 mmピッチ。長さと種類は、TPS43が届いてから決める。
- **トラックパッド：** カバー板は使わない。TPS43 の表面を直接触る（上フレームの窓は 41×38 mm、ふちが TPS43 の外周 1 mm にかかって下から押さえる。表面はケース上面から 0.5 mm 下がる）。
  - 表面の手触りが気になる場合は、あとから厚さ 0.1〜0.2 mm 程度のつや消しフィルムを貼れる（反応への影響は小さい見込みだが不確か）。
- **トラックパッド下の PORON：** 約 4 mm（底板の補強リブの上から TPS43 の裏まで約 5.1 mm。TPS43 裏の部品の高さに合わせて、軽く当たる厚さに調整）。
- **ゴム足：** YAHATA（八幡ねじ）Slim Flex ミニパット φ6 mm の**ハード**。手前用に「1.5×6ハード」×4、奥用に「3×6ハード」×4（各40個入り）。底板の8か所のくぼみ（φ6.6、深さ0.5 mm）に貼る。奥が1.5 mm高くなり、約1.2°傾く。

- **PORON シート（厚さ 3.0 mm、柔らかめ）**：約 280×110 mm が1枚分。底板の支えの隙間に入れて、ケース内の響きを抑える。
  - 型紙：`case-results` ブランチの `case/poron_3mm_A4.pdf`（A4横、等倍で印刷）と `poron_3mm.dxf`。
  - 電池のくぼみと、電池の線を通す道には入れない。
  - **厚さは 3.0 mm 以下にする**（くぼみは深さ 3.3 mm）。厚すぎると基板を押し上げ、キーが押しっぱなしになるおそれがある。

## 4. 組み立て順
1. 上フレームを裏返し、**0.5u×0.5u キーキャップ（BTキーとMキー）、リセットボタン、TPS43 を下から入れる**。TPS43 は表面を下（窓側）にして、付属の両面テープで窓のふちに貼る。
2. Tadpole Pin 9本を、上フレームの柱の穴に差し込む。
3. 基板と電池をつなぎ、FFC で TPS43 と J3 をつなぐ。
4. 基板を、Tadpole の棒が基板の穴を通るように上フレームにかぶせる（USB-Cと電源スイッチを後ろ側の切り欠きに合わせる）。
5. 底板に電池・PORON を入れ、上フレームの内側に下から押し込む（爪8か所が「パチッ」と入る）。外すときは底板をまっすぐ下に引く。
6. ACCキーキャップを上から押し込む（四隅のフックがプレートの下に引っかかる）。

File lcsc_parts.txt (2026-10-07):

# LCSC parts whose KiCad footprints are fetched by .github/workflows/lcsc.yml (easyeda2kicad)
C2906290  USB-C SHOU HAN TYPE-C 16P CB1.6 073 (mid-mount)
C965847   XINGLIGHT XL-2012SURSYGC bicolour LED
C5213729  HCTL HC-FPC-05-10-6RLTAG FPC 6P 0.5mm
C202383   ALPS SKRAAWE010
C5271144  Azoteq IQS550 (trackpad board)
C19666    4.7uF (C_0603)  - BOM part, fetched for the JLC rotation check
C19702    10uF (C_0603)  - BOM part, fetched for the JLC rotation check
C14663    100nF (C_0603)  - BOM part, fetched for the JLC rotation check
C81598    1N4148W (D_SOD-123)  - BOM part, fetched for the JLC rotation check
C8598     B5819W (D_SOD-123)  - BOM part, fetched for the JLC rotation check
C165948   USB-C (USB_C_HRO_TYPE-C-31-M-12)  - BOM part, fetched for the JLC rotation check
C160402   BATTERY (JST_SH_SM02B-SRSS-TB)  - BOM part, fetched for the JLC rotation check
C2286     RED (LED_0603)  - BOM part, fetched for the JLC rotation check
C15127    AO3401A (SOT-23)  - BOM part, fetched for the JLC rotation check
C23186    5.1k (R_0603)  - BOM part, fetched for the JLC rotation check
C25804    10k (R_0603)  - BOM part, fetched for the JLC rotation check
C21190    1k (R_0603)  - BOM part, fetched for the JLC rotation check
C25803    100k (R_0603)  - BOM part, fetched for the JLC rotation check
C23162    4.7k (R_0603)  - BOM part, fetched for the JLC rotation check
C1121891  RESET (SW_TS-1928-B)  - BOM part, fetched for the JLC rotation check
C221841   POWER (SW_SPDT_PCM12)  - BOM part, fetched for the JLC rotation check
C5118826  MDBT50Q-1MV2 (Raytac_MDBT50Q)  - BOM part, fetched for the JLC rotation check
C7519     USBLC6-2SC6 (SOT-23-6)  - BOM part, fetched for the JLC rotation check
C424093   MCP73831 (SOT-23-5)  - BOM part, fetched for the JLC rotation check

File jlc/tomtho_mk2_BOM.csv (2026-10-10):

Comment | Designator | Footprint | LCSC Part # | Qty | MPN | Note
4.7uF | C1,C4,C6,C7 | C_0603 | C19666 | 4 | CL10A475KO8NNNC | 16V X5R
10uF | C2 | C_0603 | C19702 | 1 | CL10A106KP8NNNC | 10V X5R
100nF | C3,C5 | C_0603 | C14663 | 2 | CC0603KRX7R9BB104 | 50V X7R
1N4148W | D1,D2,D3,D4,D5,D6,D7,D8,D9,D10,D11,D12,D13,D14,D15,D16,D17,D18,D19,D20,D21,D22,D23,D24,D25,D26,D27,D28,D29,D30,D31,D32,D33,D34,D35,D36,D37,D38,D39,D40,D41,D42,D43,D44,D45,D46,D47,D48,D49,D50,D51,D52,D53,D54,D55,D56,D57,D58,D59,D60,D61,D62,D63,D64,D65,D66 | D_SOD-123 | C81598 | 66 | 1N4148W | Switching diode
B5819W | D101 | D_SOD-123 | C8598 | 1 | B5819W SL | VBUS -> VSYS
USB-C | J1 | USB_C_HRO_TYPE-C-31-M-12 | C165948 | 1 | TYPE-C-31-M-12 | USB2.0 Type-C receptacle, top mount (sits in the free area under the case top)
BATTERY | J2 | JST_SH_SM02B-SRSS-TB | C160402 | 1 | SM02B-SRSS-TB(LF)(SN) | LiPo 1S (protected cell), check polarity!
TRACKPAD | J3 | FPC_0.5mm_6P_HC | C5213729 | 1 | HC-FPC-05-10-6RLTAG | To Azoteq TPS43 trackpad module (FFC 6P 0.5 mm)
RED | LED1 | LED_0603 | C2286 | 1 | KT-0603R | Charge indicator (on while charging)
XL-2012SURSYGC | LED2,LED3,LED4,LED5 | LED_XL-2012_Bicolor | C965847 | 4 | XL-2012SURSYGC | BT1 profile LED (yellow-green die used, red unused)
AO3401A | Q1 | SOT-23 | C15127 | 1 | AO3401A | Battery -> VSYS when no USB
5.1k | R1,R2 | R_0603 | C23186 | 2 | 0603WAF5101T5E | CC pull-down
4.7k | R3,R11,R12 | R_0603 | C23162 | 3 | 0603WAF4701T5E | Ichg = 1000V/4.7k = 213mA (0.2-0.5C for an 800-1000 mAh cell)
1k | R4,R6,R7,R8,R9,R10 | R_0603 | C21190 | 6 | 0603WAF1001T5E | LED resistor
100k | R5 | R_0603 | C25803 | 1 | 0603WAF1003T5E | Q1 gate pull-down
SKRAAWE010 | SW1,SW2,SW3,SW4,SW5,SW6,SW7,SW8,SW9,SW10,SW11,SW12,SW13,SW14,SW15,SW16,SW17,SW18,SW19,SW20,SW21,SW22,SW23,SW24,SW25,SW26,SW27,SW28,SW29,SW30,SW31,SW32,SW33,SW34,SW35,SW36,SW37,SW38,SW39,SW40,SW41,SW42,SW43,SW44,SW45,SW46,SW47,SW48,SW49,SW50,SW51,SW52,SW53,SW54,SW55,SW56,SW57,SW58,SW59,SW60,SW61,SW62,SW63,SW64,SW65,SW66 | SW_ALPS_SKRA_6.2mm | C202383 | 66 | SKRAAWE010 | key "`" - ALPS SKRA 6.2mm tact
RESET | SW101 | SW_TS-1928-B | C1121891 | 1 | TS-1928-B | Reset (double-tap = UF2 bootloader)
POWER | SW102 | SW_SPDT_PCM12 | C221841 | 1 | PCM12SMTR | Power slide switch (pin3 = OFF, open)
MDBT50Q-1MV2 | U1 | Raytac_MDBT50Q | C5118826 | 1 | MDBT50Q-1MV2 | nRF52840 BLE module, chip antenna, TELEC certified
USBLC6-2SC6 | U2 | SOT-23-6 | C7519 | 1 | USBLC6-2SC6 | USB ESD protection
MCP73831 | U3 | SOT-23-5 | C424093 | 1 | MCP73831T-2ACI/OT | Li-Po charger 4.2V

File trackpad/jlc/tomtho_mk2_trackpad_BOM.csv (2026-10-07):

Comment | Designator | Footprint | LCSC Part # | Qty
100n | C1,C6 | C_0603_1608Metric | C14663 | 2
100p | C2,C4 | C_0603_1608Metric | C14858 | 2
1u | C3,C5 | C_0603_1608Metric | C15849 | 2
Conn_01x06 | J1 | Jushuo_AFC07-S06FCA-00_1x6-1MP_P0.50_Horizontal-JLC | C11048 | 1
4.7k | R1,R2 | R_0603_1608Metric | C23162 | 2
1k | R3,R4,R5,R6,R7,R8,R9,R10,R11,R12 | R_0603_1608Metric | C21190 | 10

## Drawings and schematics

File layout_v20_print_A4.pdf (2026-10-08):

## tomtho-slim mk2 レイアウト v20 実寸印刷用

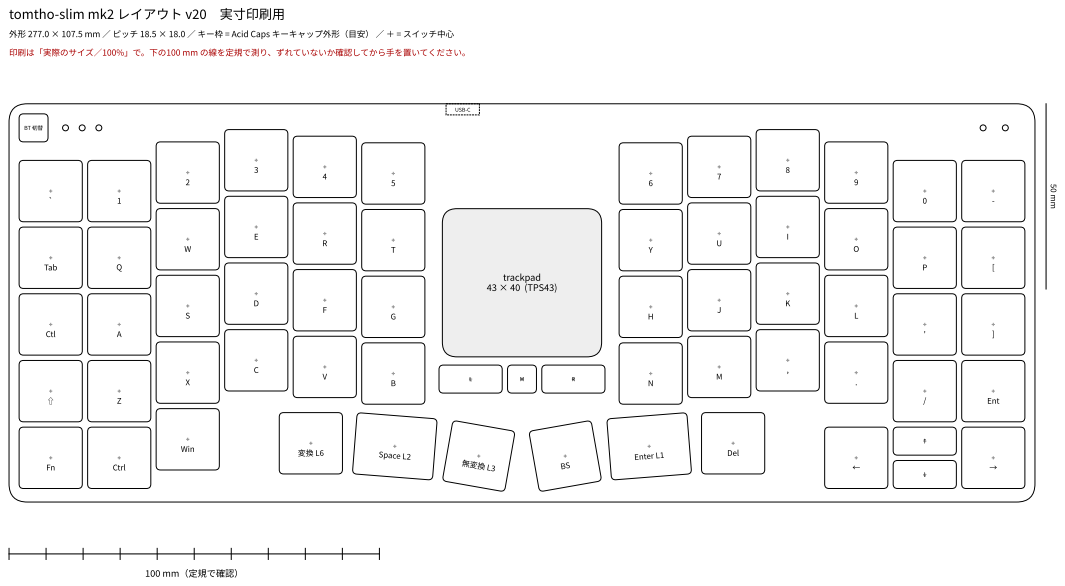
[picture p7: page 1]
trackpad 43 × 40 (TPS43); Tab; Ctl; Ent; Ctrl; Win; Space L2; 無変換 L3; Enter L1 Del; USB-C; 100 mm（定規で確認）

外形 277.0 × 107.5 mm ／ ピッチ 18.5 × 18.0 ／ キー枠 = Acid Caps キーキャップ外形（目安） ／ ＋ = スイッチ中心
印刷は「実際のサイズ／100%」で。下の100 mm の線を定規で測り、ずれていないか確認してから手を置いてください。

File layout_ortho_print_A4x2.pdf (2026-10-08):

# オーソリニア版（ずらし無し・親指も一直線）（1/2 左） 赤い点線で右ページと重ねて貼る。実際のサイズ／100% で印刷

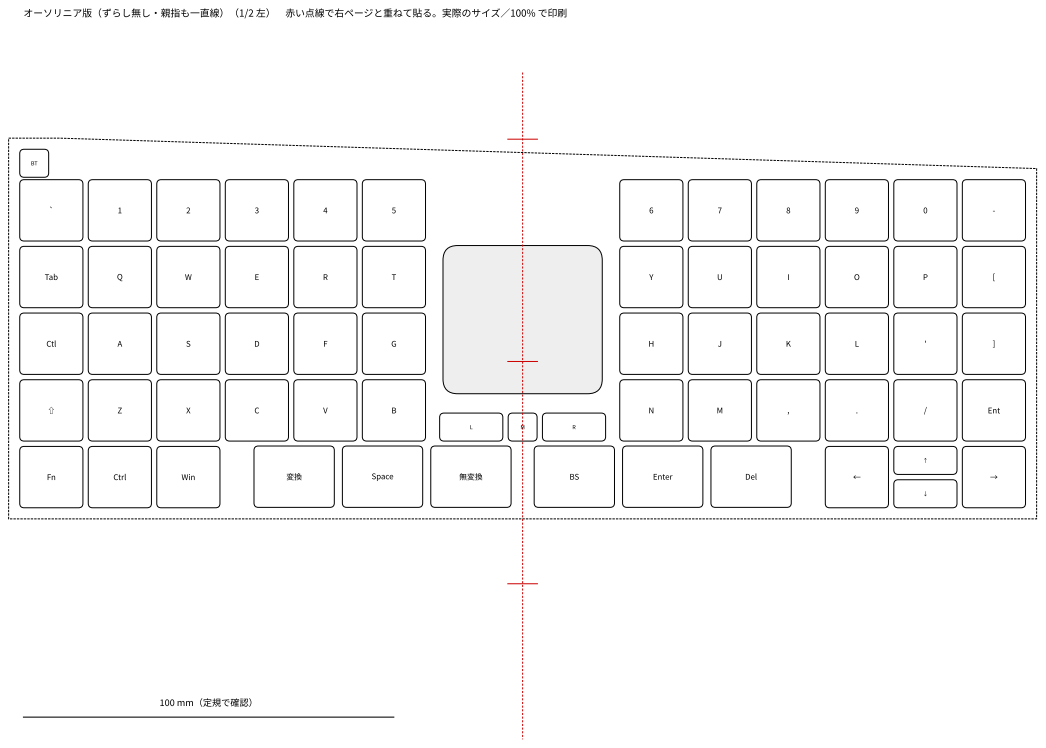
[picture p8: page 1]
Tab; Ctl; Ent; Ctrl; Win; Space; 無変換; Enter; Del; 100 mm（定規で確認）

# オーソリニア版（ずらし無し・親指も一直線）（2/2 右） 赤い点線で左ページと重ねて貼る。実際のサイズ／100% で印刷

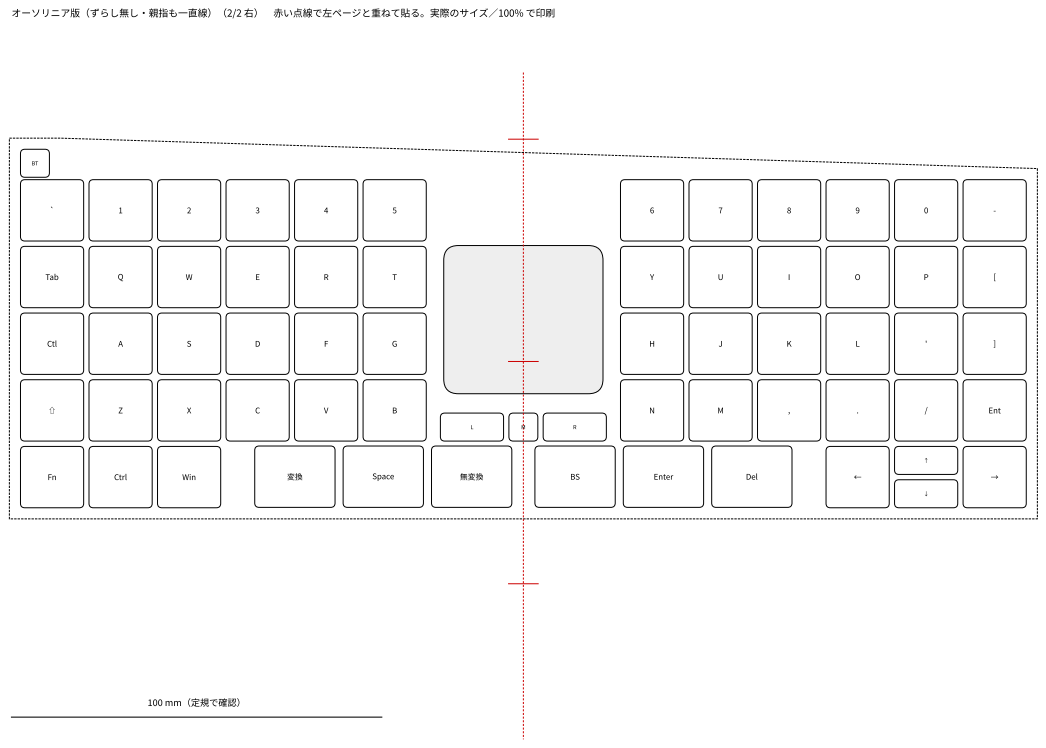
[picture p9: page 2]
Tab; Ctl; Ent; Ctrl; Win; Space; 無変換; Enter; Del; 100 mm（定規で確認）

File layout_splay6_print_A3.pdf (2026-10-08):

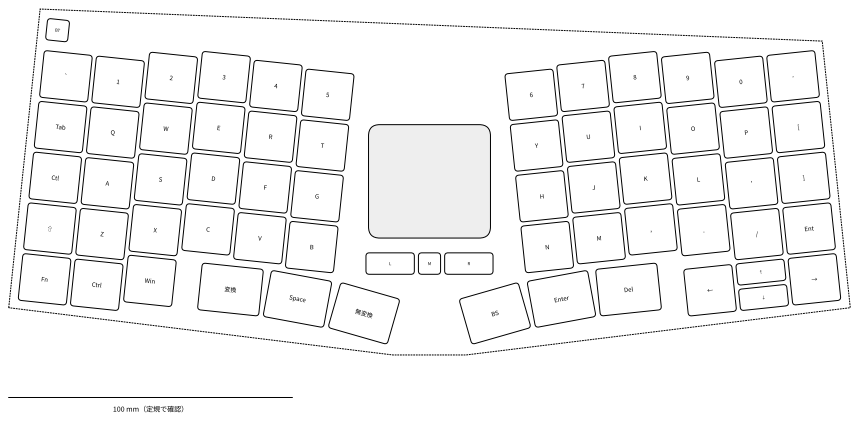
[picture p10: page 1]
Tab; Ctl; Ent; Fn Ctrl; Win; Space; 無変換; Enter; Del; 100 mm（定規で確認）

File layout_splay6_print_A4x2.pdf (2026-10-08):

# 左右を 6° 開いた版（1/2 左） 赤い点線で右ページと重ねて貼る。実際のサイズ／100% で印刷

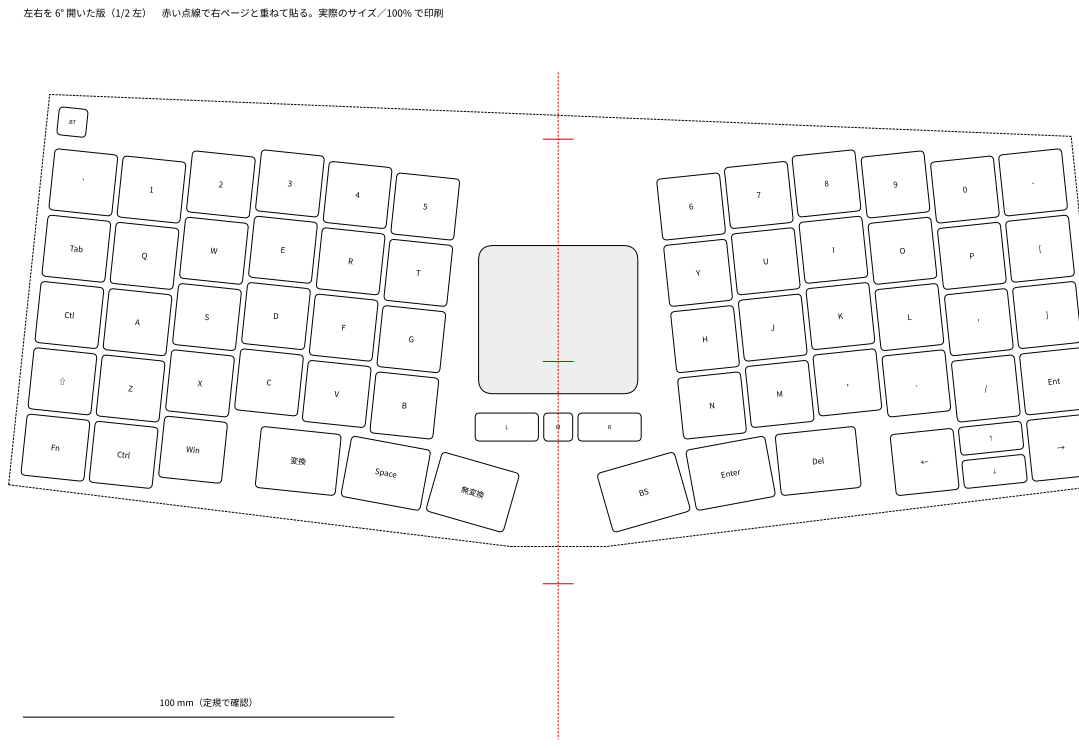
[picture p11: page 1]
Tab; Ctl; Ent; Fn Ctrl; Win; Space; 無変換; Enter; Del; 100 mm（定規で確認）

# 左右を 6° 開いた版（2/2 右） 赤い点線で左ページと重ねて貼る。実際のサイズ／100% で印刷

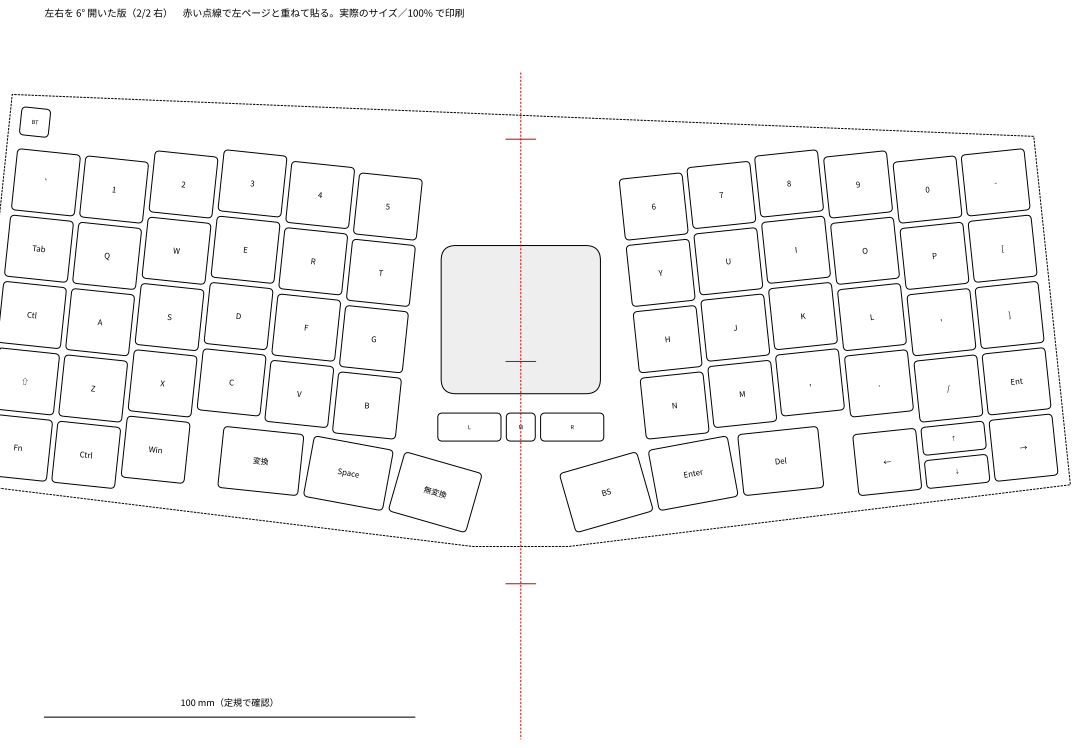
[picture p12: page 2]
Tab; Ctl; Ent; Fn Ctrl; Win; Space; 無変換; Enter; Del; 100 mm（定規で確認）

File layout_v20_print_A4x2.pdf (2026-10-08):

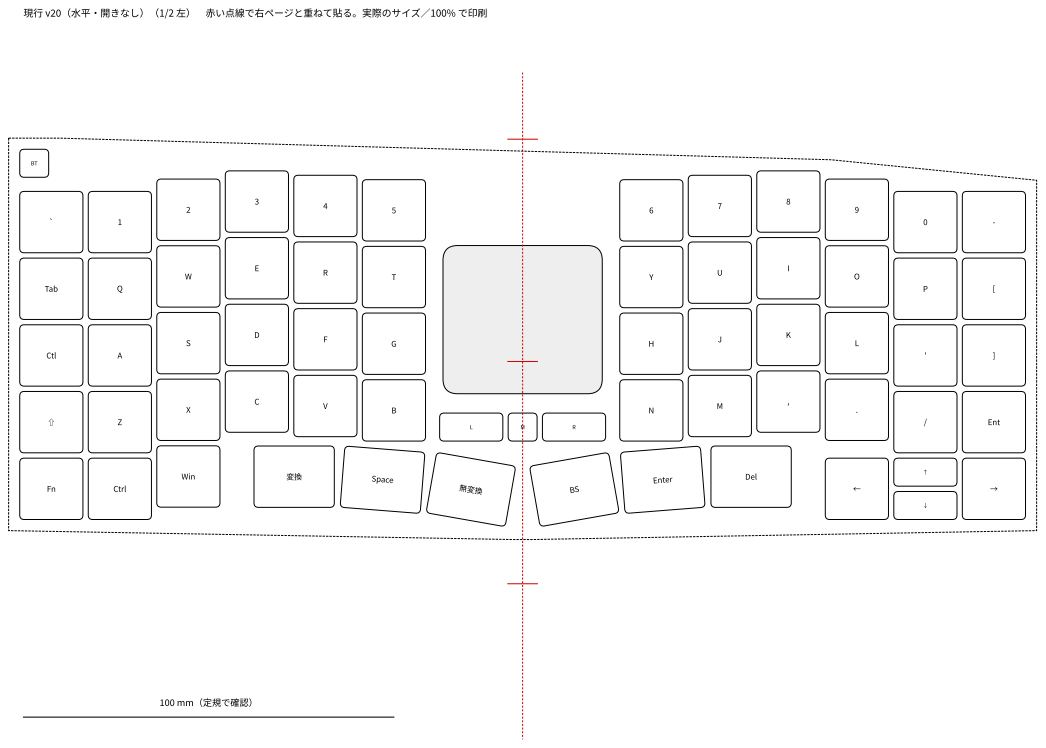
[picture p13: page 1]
Tab; Ctl; Ent; Ctrl; Win; Space; 無変換; Enter Del; 100 mm（定規で確認）

現行 v20（水平・開きなし）（1/2 左）　赤い点線で右ページと重ねて貼る。実際のサイズ／100% で印刷

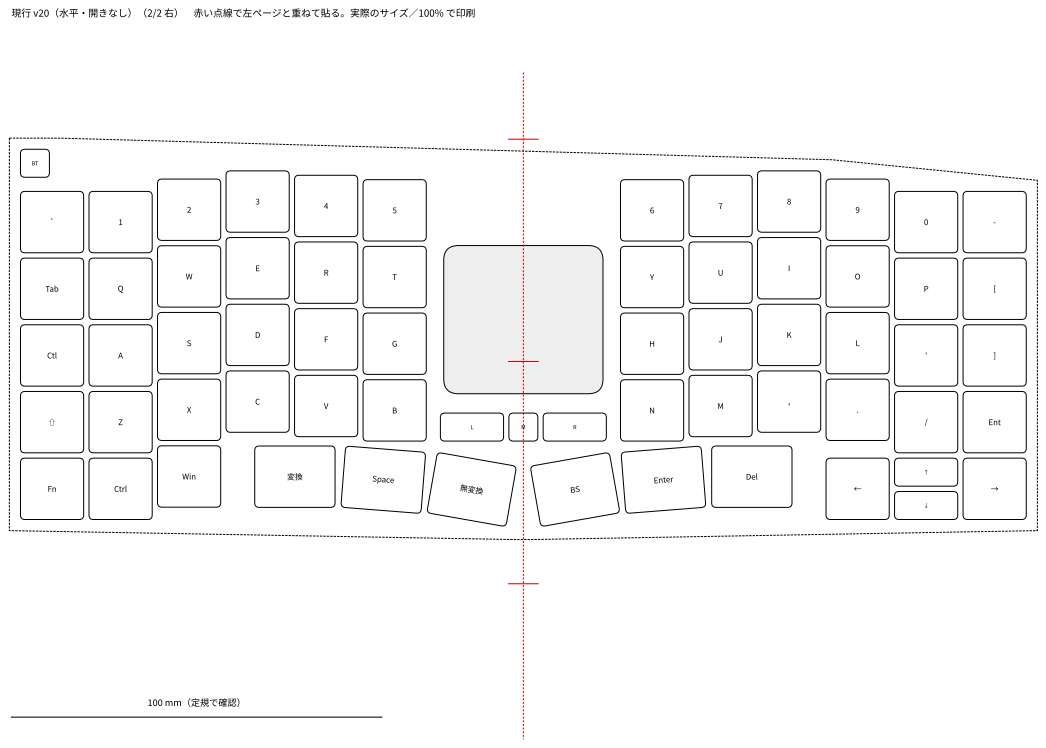
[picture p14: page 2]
Tab; Ctl; Ent; Ctrl; Win; Space; 無変換; Enter Del; 100 mm（定規で確認）

現行 v20（水平・開きなし）（2/2 右）　赤い点線で左ページと重ねて貼る。実際のサイズ／100% で印刷

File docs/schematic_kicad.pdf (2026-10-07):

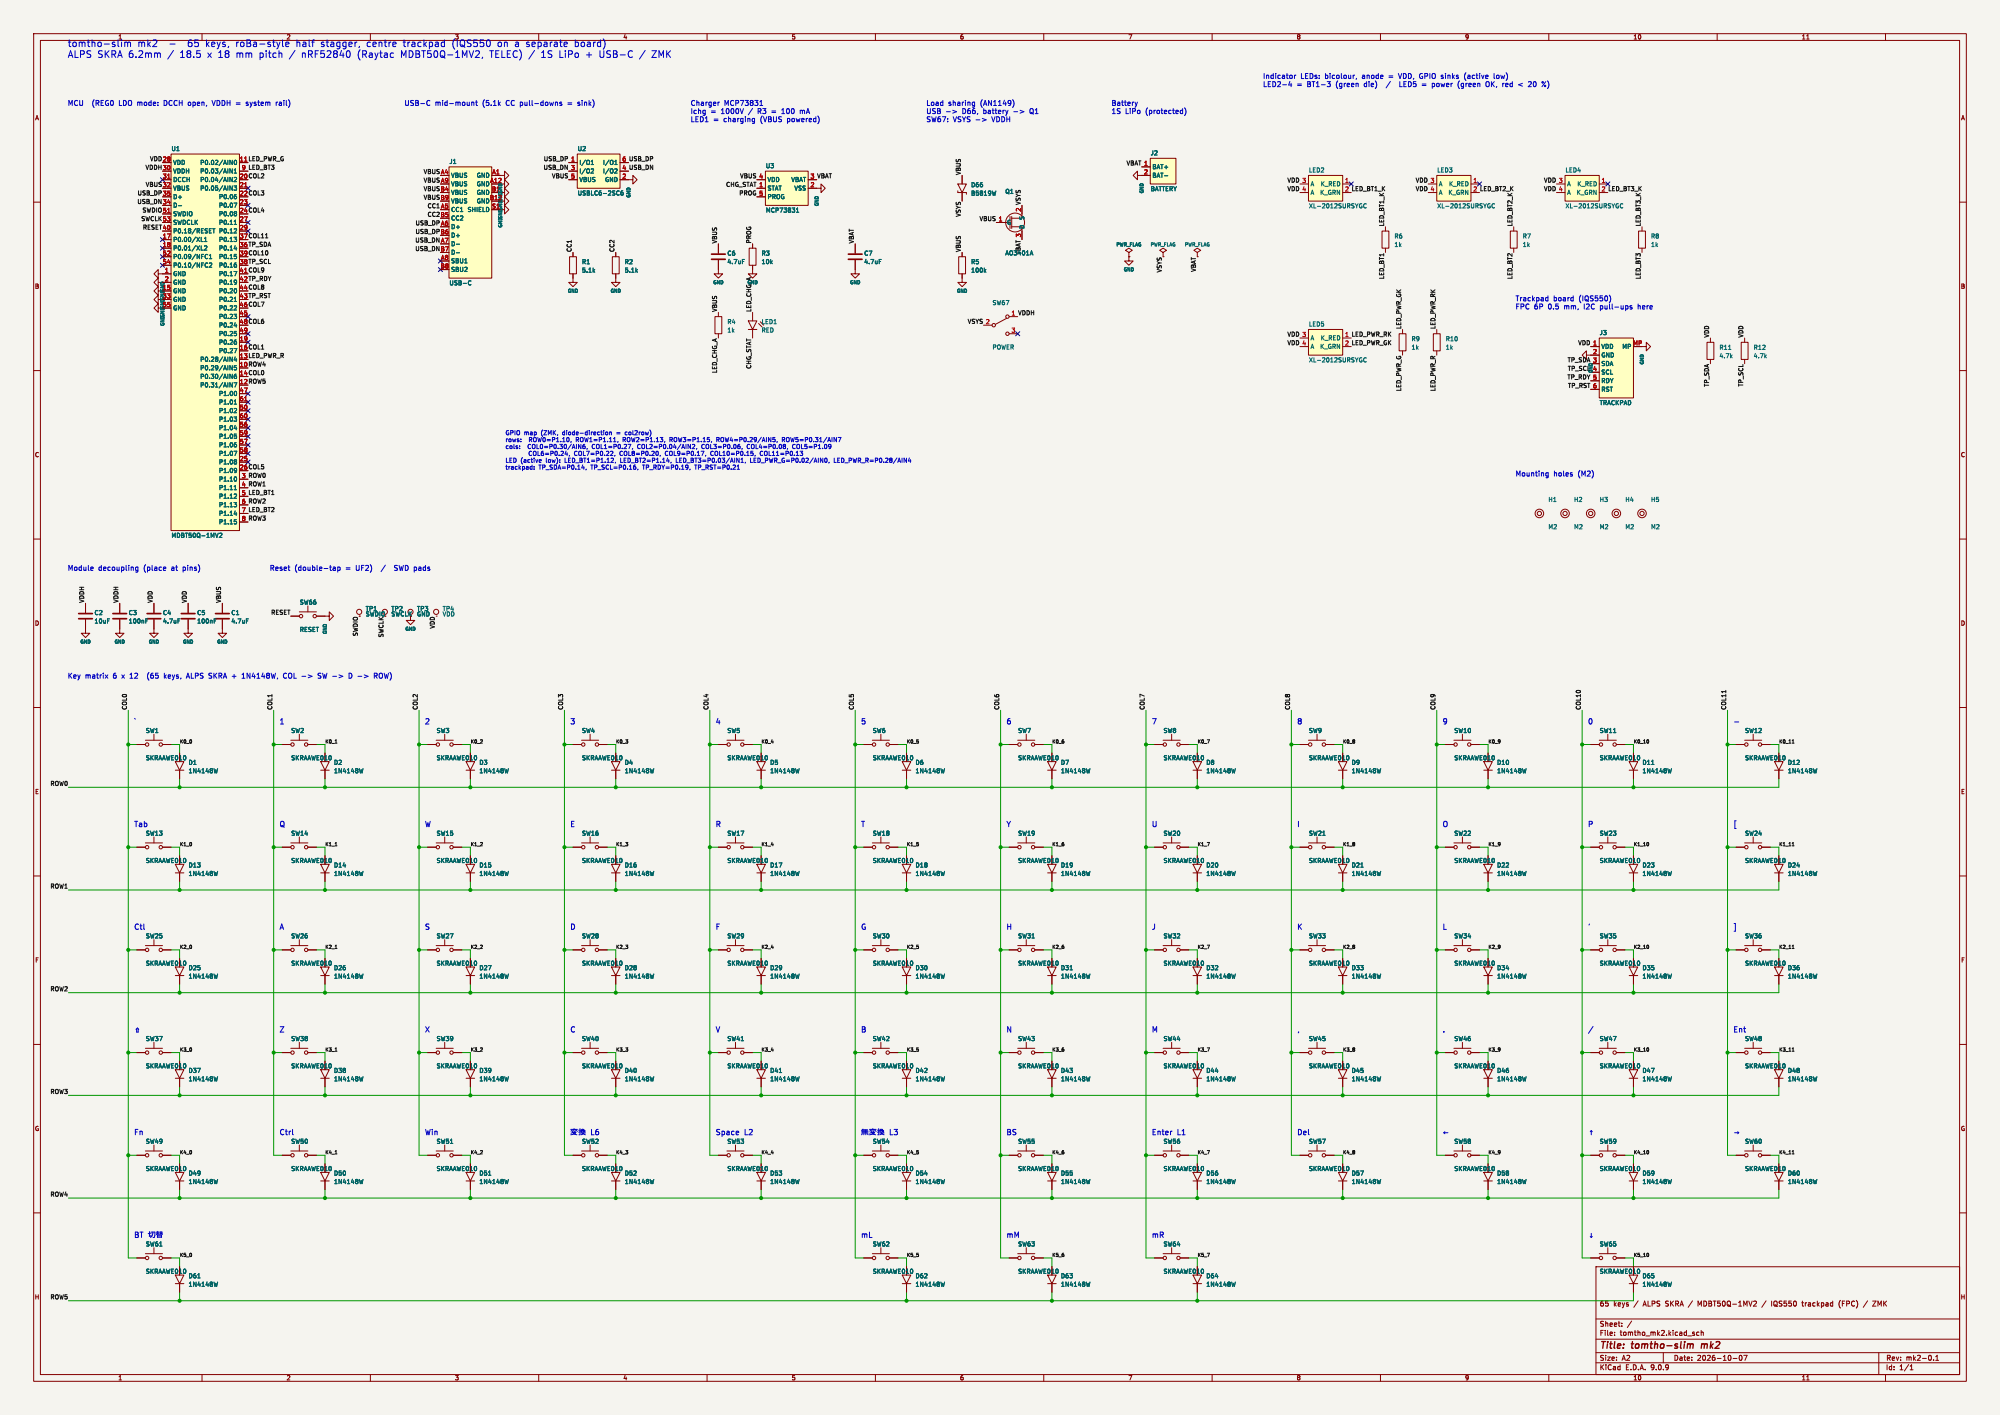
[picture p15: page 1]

MCU (REG0 LDO mode: DCCH open, VDDH = system rail)
U1 MDBT50Q-1MV2

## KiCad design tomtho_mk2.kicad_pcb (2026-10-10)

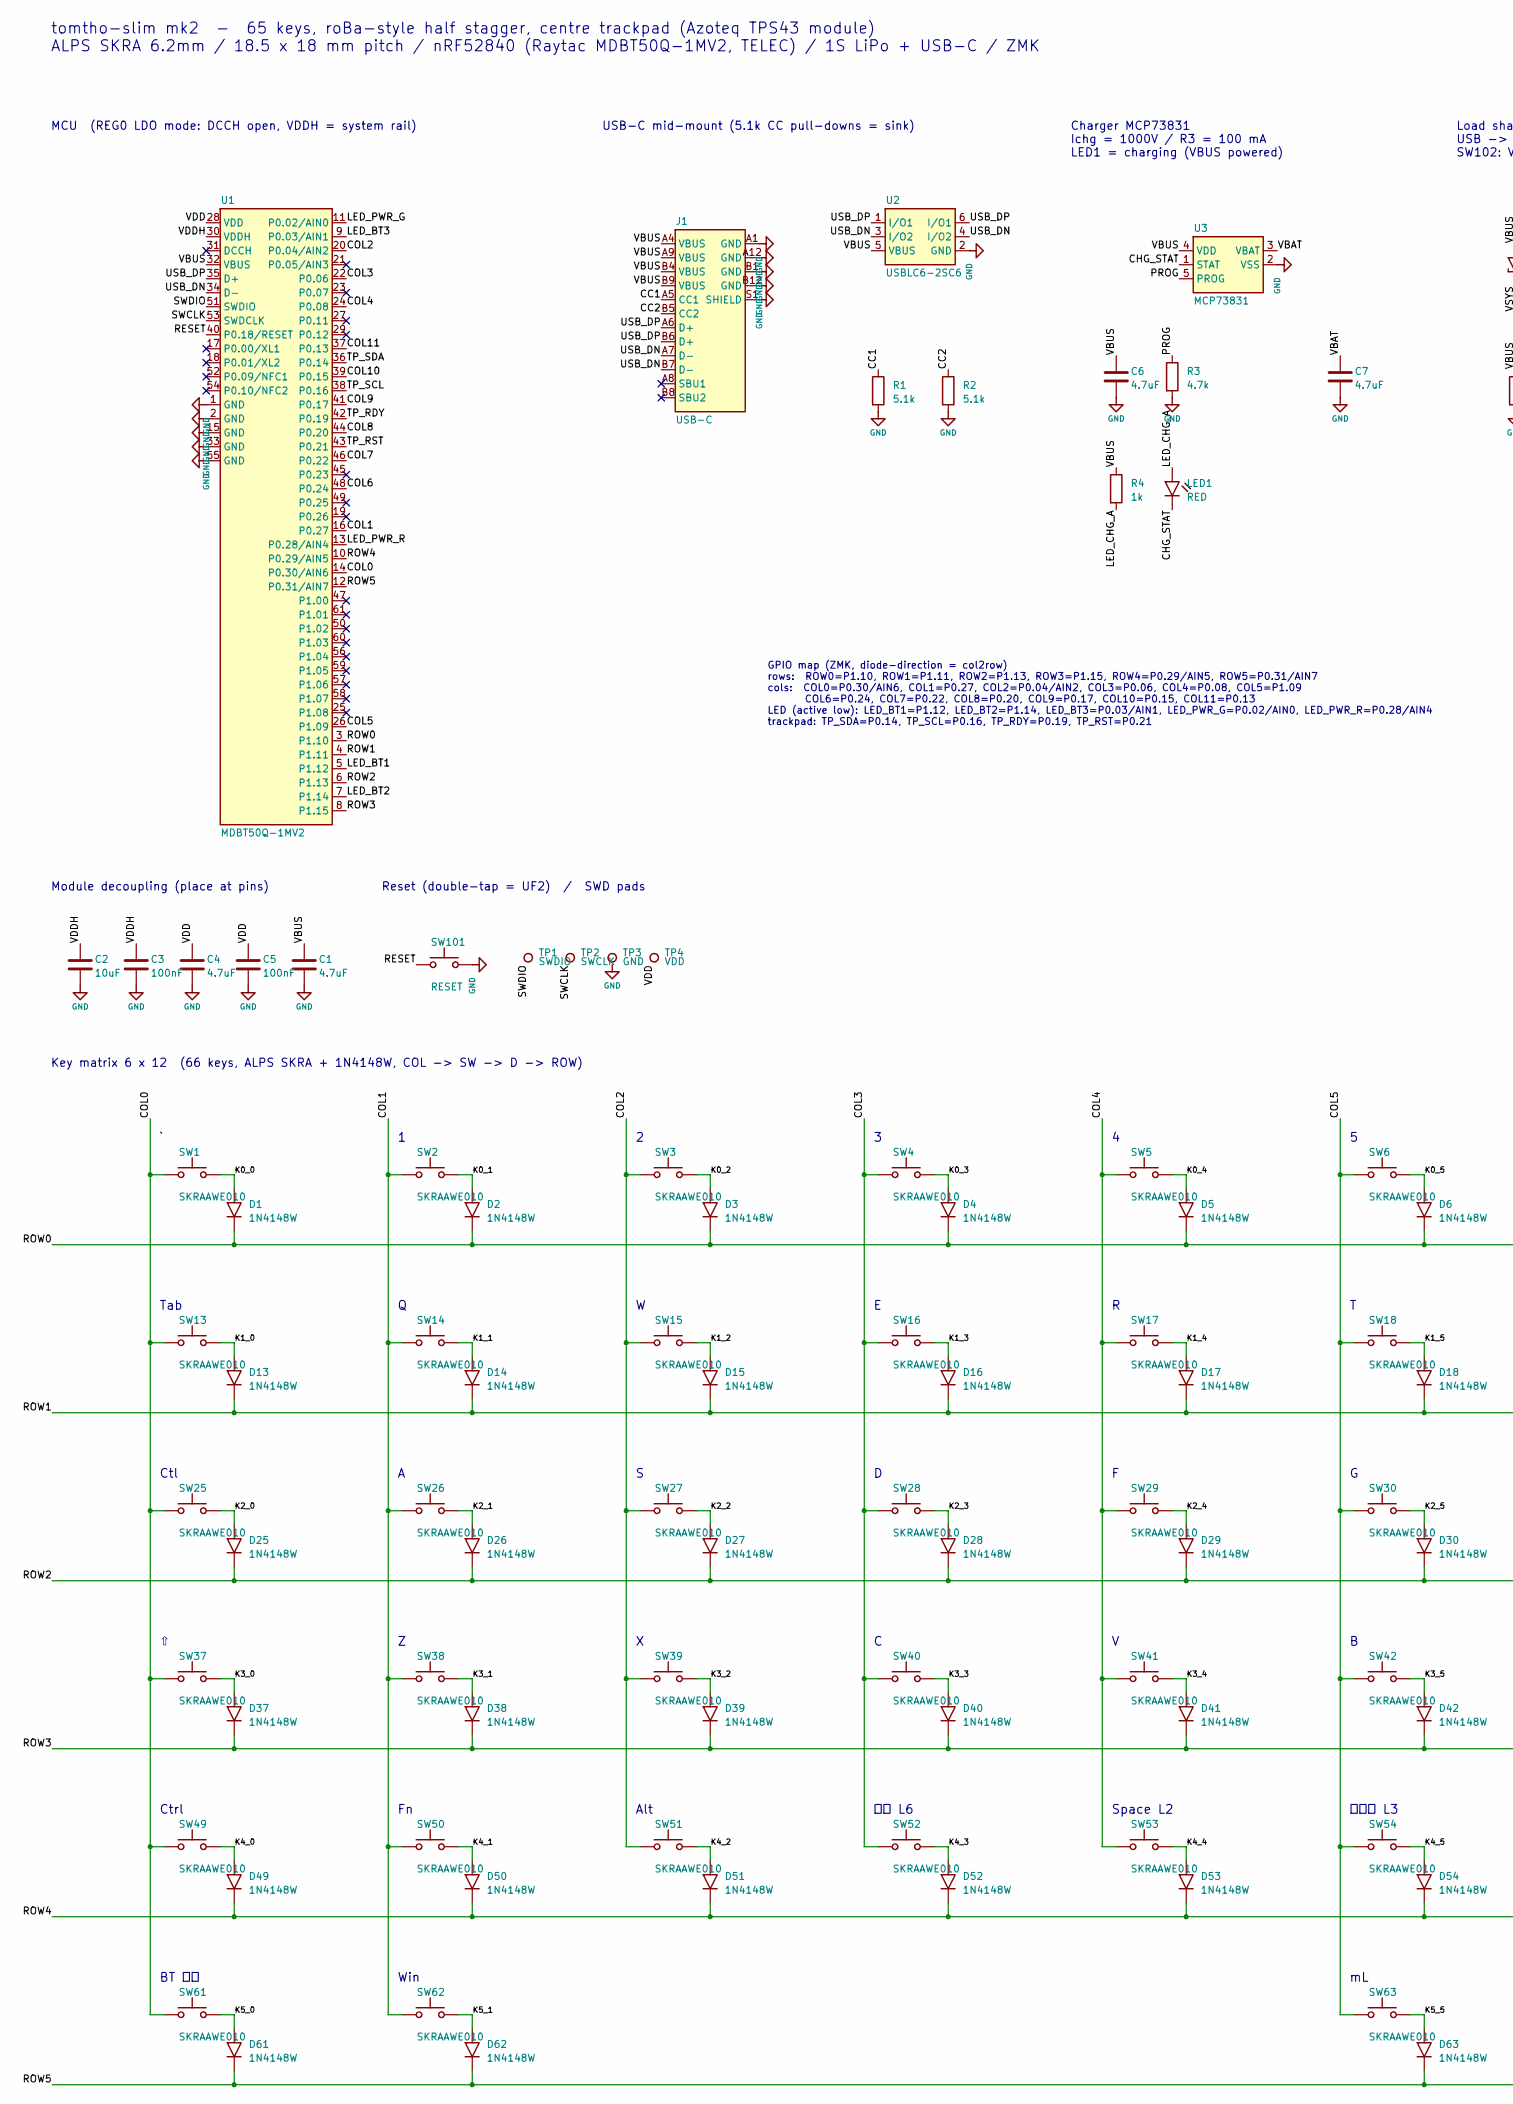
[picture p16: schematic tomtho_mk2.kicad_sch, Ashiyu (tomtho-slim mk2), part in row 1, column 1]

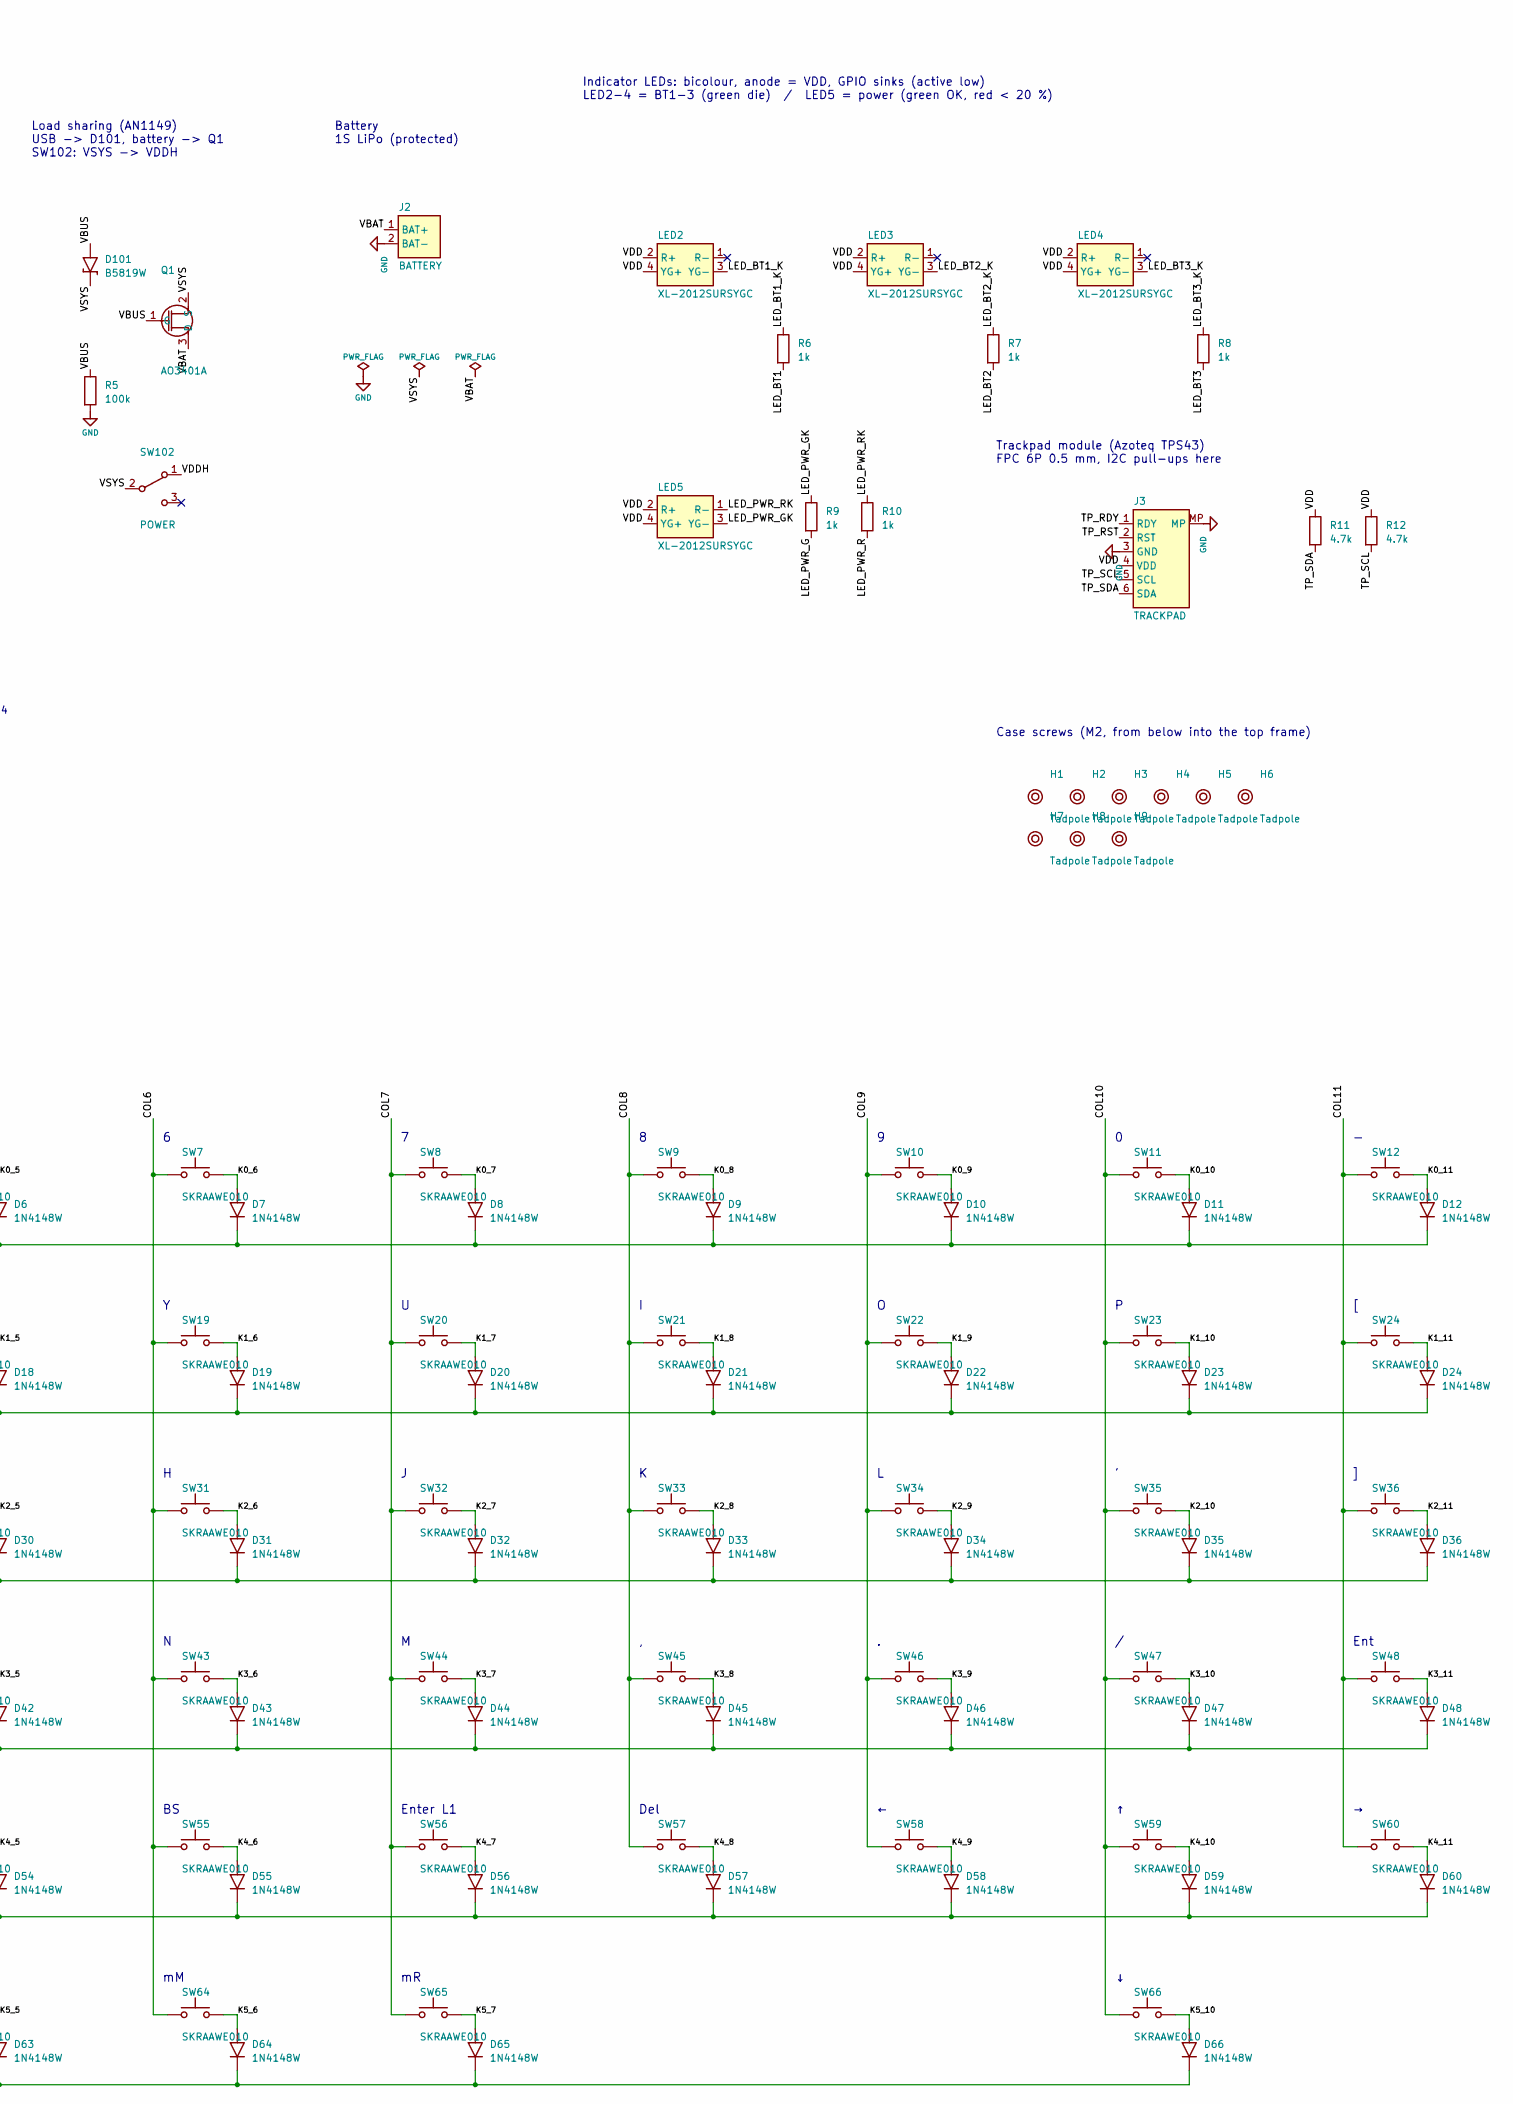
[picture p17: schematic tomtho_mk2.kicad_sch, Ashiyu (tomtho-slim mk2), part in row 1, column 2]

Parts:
C1, C4, C6, C7: 4.7uF; C_0603; MPN CL10A475KO8NNNC; LCSC C19666
C2: 10uF; C_0603; MPN CL10A106KP8NNNC; LCSC C19702
C3, C5: 100nF; C_0603; MPN CC0603KRX7R9BB104; LCSC C14663
D1, D2, D3, D4, D5, D6, D7, D8, D9, D10, D11, D12, D13, D14, D15, D16, D17, D18, D19, D20, D21, D22, D23, D24, D25, D26, D27, D28, D29, D30, D31, D32, D33, D34, D35, D36, D37, D38, D39, D40, D41, D42, D43, D44, D45, D46, D47, D48, D49, D50, D51, D52, D53, D54, D55, D56, D57, D58, D59, D60, D61, D62, D63, D64, D65, D66: 1N4148W; D_SOD-123; MPN 1N4148W; LCSC C81598
D101: B5819W; D_SOD-123; MPN B5819W SL; LCSC C8598
H1, H2, H3, H4, H5, H6, H7, H8, H9: Tadpole; Tadpole_D3.0_NPTH
J1: USB-C; USB_C_HRO_TYPE-C-31-M-12; MPN TYPE-C-31-M-12; LCSC C165948
J2: BATTERY; JST_SH_SM02B-SRSS-TB; MPN SM02B-SRSS-TB(LF)(SN); LCSC C160402
J3: TRACKPAD; FPC_0.5mm_6P_HC; MPN HC-FPC-05-10-6RLTAG; LCSC C5213729
LED1: RED; LED_0603; MPN KT-0603R; LCSC C2286
LED2, LED3, LED4, LED5: XL-2012SURSYGC; LED_XL-2012_Bicolor; MPN XL-2012SURSYGC; LCSC C965847
Q1: AO3401A; SOT-23; MPN AO3401A; LCSC C15127
R1, R2: 5.1k; R_0603; MPN 0603WAF5101T5E; LCSC C23186
R3, R11, R12: 4.7k; R_0603; MPN 0603WAF4701T5E; LCSC C23162
R4, R6, R7, R8, R9, R10: 1k; R_0603; MPN 0603WAF1001T5E; LCSC C21190
R5: 100k; R_0603; MPN 0603WAF1003T5E; LCSC C25803
SW1, SW2, SW3, SW4, SW5, SW6, SW7, SW8, SW9, SW10, SW11, SW12, SW13, SW14, SW15, SW16, SW17, SW18, SW19, SW20, SW21, SW22, SW23, SW24, SW25, SW26, SW27, SW28, SW29, SW30, SW31, SW32, SW33, SW34, SW35, SW36, SW37, SW38, SW39, SW40, SW41, SW42, SW43, SW44, SW45, SW46, SW47, SW48, SW49, SW50, SW51, SW52, SW53, SW54, SW55, SW56, SW57, SW58, SW59, SW60, SW61, SW62, SW63, SW64, SW65, SW66: SKRAAWE010; SW_ALPS_SKRA_6.2mm; MPN SKRAAWE010; LCSC C202383
SW101: RESET; SW_TS-1928-B; MPN TS-1928-B; LCSC C1121891
SW102: POWER; SW_SPDT_PCM12; MPN PCM12SMTR; LCSC C221841
TP1: SWDIO; TestPoint_Pad_D1.0mm
TP2: SWCLK; TestPoint_Pad_D1.0mm
TP3: GND; TestPoint_Pad_D1.0mm
TP4: VDD; TestPoint_Pad_D1.0mm
U1: MDBT50Q-1MV2; Raytac_MDBT50Q; MPN MDBT50Q-1MV2; LCSC C5118826
U2: USBLC6-2SC6; SOT-23-6; MPN USBLC6-2SC6; LCSC C7519
U3: MCP73831; SOT-23-5; MPN MCP73831T-2ACI/OT; LCSC C424093

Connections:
/CC1: J1.A5 (CC1), R1.1
/CC2: J1.B5 (CC2), R2.1
/CHG_STAT: LED1.1 (K), U3.1 (STAT)
/COL0: SW1.1, SW13.1, SW25.1, SW37.1, SW49.1, SW61.1, U1.14 (P0.30/AIN6)
/COL1: SW2.1, SW14.1, SW26.1, SW38.1, SW50.1, SW62.1, U1.16 (P0.27)
/COL2: SW3.1, SW15.1, SW27.1, SW39.1, SW51.1, U1.20 (P0.04/AIN2)
/COL3: SW4.1, SW16.1, SW28.1, SW40.1, SW52.1, U1.22 (P0.06)
/COL4: SW5.1, SW17.1, SW29.1, SW41.1, SW53.1, U1.24 (P0.08)
/COL5: SW6.1, SW18.1, SW30.1, SW42.1, SW54.1, SW63.1, U1.26 (P1.09)
/COL6: SW7.1, SW19.1, SW31.1, SW43.1, SW55.1, SW64.1, U1.48 (P0.24)
/COL7: SW8.1, SW20.1, SW32.1, SW44.1, SW56.1, SW65.1, U1.46 (P0.22)
/COL8: SW9.1, SW21.1, SW33.1, SW45.1, SW57.1, U1.44 (P0.20)
/COL9: SW10.1, SW22.1, SW34.1, SW46.1, SW58.1, U1.41 (P0.17)
/COL10: SW11.1, SW23.1, SW35.1, SW47.1, SW59.1, SW66.1, U1.39 (P0.15)
/COL11: SW12.1, SW24.1, SW36.1, SW48.1, SW60.1, U1.37 (P0.13)
/K0_0: D1.2 (A), SW1.2
/K0_1: D2.2 (A), SW2.2
/K0_2: D3.2 (A), SW3.2
/K0_3: D4.2 (A), SW4.2
/K0_4: D5.2 (A), SW5.2
/K0_5: D6.2 (A), SW6.2
/K0_6: D7.2 (A), SW7.2
/K0_7: D8.2 (A), SW8.2
/K0_8: D9.2 (A), SW9.2
/K0_9: D10.2 (A), SW10.2
/K0_10: D11.2 (A), SW11.2
/K0_11: D12.2 (A), SW12.2
/K1_0: D13.2 (A), SW13.2
/K1_1: D14.2 (A), SW14.2
/K1_2: D15.2 (A), SW15.2
/K1_3: D16.2 (A), SW16.2
/K1_4: D17.2 (A), SW17.2
/K1_5: D18.2 (A), SW18.2
/K1_6: D19.2 (A), SW19.2
/K1_7: D20.2 (A), SW20.2
/K1_8: D21.2 (A), SW21.2
/K1_9: D22.2 (A), SW22.2
/K1_10: D23.2 (A), SW23.2
/K1_11: D24.2 (A), SW24.2
/K2_0: D25.2 (A), SW25.2
/K2_1: D26.2 (A), SW26.2
/K2_2: D27.2 (A), SW27.2
/K2_3: D28.2 (A), SW28.2
/K2_4: D29.2 (A), SW29.2
/K2_5: D30.2 (A), SW30.2
/K2_6: D31.2 (A), SW31.2
/K2_7: D32.2 (A), SW32.2
/K2_8: D33.2 (A), SW33.2
/K2_9: D34.2 (A), SW34.2
/K2_10: D35.2 (A), SW35.2
/K2_11: D36.2 (A), SW36.2
/K3_0: D37.2 (A), SW37.2
/K3_1: D38.2 (A), SW38.2
/K3_2: D39.2 (A), SW39.2
/K3_3: D40.2 (A), SW40.2
/K3_4: D41.2 (A), SW41.2
/K3_5: D42.2 (A), SW42.2
/K3_6: D43.2 (A), SW43.2
/K3_7: D44.2 (A), SW44.2
/K3_8: D45.2 (A), SW45.2
/K3_9: D46.2 (A), SW46.2
/K3_10: D47.2 (A), SW47.2
/K3_11: D48.2 (A), SW48.2
/K4_0: D49.2 (A), SW49.2
/K4_1: D50.2 (A), SW50.2
/K4_2: D51.2 (A), SW51.2
/K4_3: D52.2 (A), SW52.2
/K4_4: D53.2 (A), SW53.2
/K4_5: D54.2 (A), SW54.2
/K4_6: D55.2 (A), SW55.2
/K4_7: D56.2 (A), SW56.2
/K4_8: D57.2 (A), SW57.2
/K4_9: D58.2 (A), SW58.2
/K4_10: D59.2 (A), SW59.2
/K4_11: D60.2 (A), SW60.2
/K5_0: D61.2 (A), SW61.2
/K5_1: D62.2 (A), SW62.2
/K5_5: D63.2 (A), SW63.2
/K5_6: D64.2 (A), SW64.2
/K5_7: D65.2 (A), SW65.2
/K5_10: D66.2 (A), SW66.2
/LED_BT1: R6.2, U1.5 (P1.12)
/LED_BT1_K: LED2.3 (YG-), R6.1
/LED_BT2: R7.2, U1.7 (P1.14)
/LED_BT2_K: LED3.3 (YG-), R7.1
/LED_BT3: R8.2, U1.9 (P0.03/AIN1)
/LED_BT3_K: LED4.3 (YG-), R8.1
/LED_CHG_A: LED1.2 (A), R4.2
/LED_PWR_G: R9.2, U1.11 (P0.02/AIN0)
/LED_PWR_GK: LED5.3 (YG-), R9.1
/LED_PWR_R: R10.2, U1.13 (P0.28/AIN4)
/LED_PWR_RK: LED5.1 (R-), R10.1
/PROG: R3.1, U3.5 (PROG)
/RESET: SW101.1, U1.40 (P0.18/RESET)
/ROW0: D1.1 (K), D2.1 (K), D3.1 (K), D4.1 (K), D5.1 (K), D6.1 (K), D7.1 (K), D8.1 (K), D9.1 (K), D10.1 (K), D11.1 (K), D12.1 (K), U1.3 (P1.10)
/ROW1: D13.1 (K), D14.1 (K), D15.1 (K), D16.1 (K), D17.1 (K), D18.1 (K), D19.1 (K), D20.1 (K), D21.1 (K), D22.1 (K), D23.1 (K), D24.1 (K), U1.4 (P1.11)
/ROW2: D25.1 (K), D26.1 (K), D27.1 (K), D28.1 (K), D29.1 (K), D30.1 (K), D31.1 (K), D32.1 (K), D33.1 (K), D34.1 (K), D35.1 (K), D36.1 (K), U1.6 (P1.13)
/ROW3: D37.1 (K), D38.1 (K), D39.1 (K), D40.1 (K), D41.1 (K), D42.1 (K), D43.1 (K), D44.1 (K), D45.1 (K), D46.1 (K), D47.1 (K), D48.1 (K), U1.8 (P1.15)
/ROW4: D49.1 (K), D50.1 (K), D51.1 (K), D52.1 (K), D53.1 (K), D54.1 (K), D55.1 (K), D56.1 (K), D57.1 (K), D58.1 (K), D59.1 (K), D60.1 (K), U1.10 (P0.29/AIN5)
/ROW5: D61.1 (K), D62.1 (K), D63.1 (K), D64.1 (K), D65.1 (K), D66.1 (K), U1.12 (P0.31/AIN7)
/SWCLK: TP2.1, U1.53 (SWDCLK)
/SWDIO: TP1.1, U1.51 (SWDIO)
/TP_RDY: J3.1 (RDY), U1.42 (P0.19)
/TP_RST: J3.2 (RST), U1.43 (P0.21)
/TP_SCL: J3.5 (SCL), R12.2, U1.38 (P0.16)
/TP_SDA: J3.6 (SDA), R11.2, U1.36 (P0.14)
/USB_DN: J1.A7 (D-), J1.B7 (D-), U1.34 (D-), U2.3 (I/O2), U2.4 (I/O2)
/USB_DP: J1.A6 (D+), J1.B6 (D+), U1.35 (D+), U2.1 (I/O1), U2.6 (I/O1)
/VBAT: C7.1, J2.1 (BAT+), Q1.3 (D), U3.3 (VBAT)
/VBUS: C1.1, C6.1, D101.2 (A), J1.A4 (VBUS), J1.A9 (VBUS), J1.B4 (VBUS), J1.B9 (VBUS), Q1.1 (G), R4.1, R5.1, U1.32 (VBUS), U2.5 (VBUS), U3.4 (VDD)
/VDD: C4.1, C5.1, J3.4 (VDD), LED2.2 (R+), LED2.4 (YG+), LED3.2 (R+), LED3.4 (YG+), LED4.2 (R+), LED4.4 (YG+), LED5.2 (R+), LED5.4 (YG+), R11.1, R12.1, TP4.1, U1.28 (VDD)
/VDDH: C2.1, C3.1, SW102.1 (A), U1.30 (VDDH)
/VSYS: D101.1 (K), Q1.2 (S), SW102.2 (C)
GND: C1.2, C2.2, C3.2, C4.2, C5.2, C6.2, C7.2, J1.A1 (GND), J1.A12 (GND), J1.B1 (GND), J1.B12 (GND), J1.S1 (SHIELD), J2.2 (BAT-), J3.3 (GND), J3.MP, R1.2, R2.2, R3.2, R5.2, SW101.2, TP3.1, U1.1 (GND), U1.2 (GND), U1.15 (GND), U1.33 (GND), U1.55 (GND), U2.2 (GND), U3.2 (VSS)

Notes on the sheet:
tomtho-slim mk2 - 65 keys, roBa-style half stagger, centre trackpad (Azoteq TPS43 module) ALPS SKRA 6.2mm / 18.5 x 18 mm pitch / nRF52840 (Raytac MDBT50Q-1MV2, TELEC) / 1S LiPo + USB-C / ZMK
MCU (REG0 LDO mode: DCCH open, VDDH = system rail)
Module decoupling (place at pins)
Reset (double-tap = UF2) / SWD pads
USB-C mid-mount (5.1k CC pull-downs = sink)
Charger MCP73831 Ichg = 1000V / R3 = 100 mA LED1 = charging (VBUS powered)
Load sharing (AN1149) USB -> D101, battery -> Q1 SW102: VSYS -> VDDH
Battery 1S LiPo (protected)
Indicator LEDs: bicolour, anode = VDD, GPIO sinks (active low) LED2-4 = BT1-3 (green die) / LED5 = power (green OK, red < 20 %)
Trackpad module (Azoteq TPS43) FPC 6P 0.5 mm, I2C pull-ups here
Case screws (M2, from below into the top frame)
GPIO map (ZMK, diode-direction = col2row) rows: ROW0=P1.10, ROW1=P1.11, ROW2=P1.13, ROW3=P1.15, ROW4=P0.29/AIN5, ROW5=P0.31/AIN7 cols: COL0=P0.30/AIN6, COL1=P0.27, COL2=P0.04/AIN2, COL3=P0.06, COL4=P0.08, COL5=P1.09 COL6=P0.24, COL7=P0.22, COL8=P0.20, COL9=P0.17, COL10=P0.15, COL11=P0.13 LED (activ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
Key matrix 6 x 12 (66 keys, ALPS SKRA + 1N4148W, COL -> SW -> D -> ROW)
Tab
Ctl
Ent
Ctrl
Alt
変換 L6
Space L2
無変換 L3
Enter L1
Del
BT 切替
Win

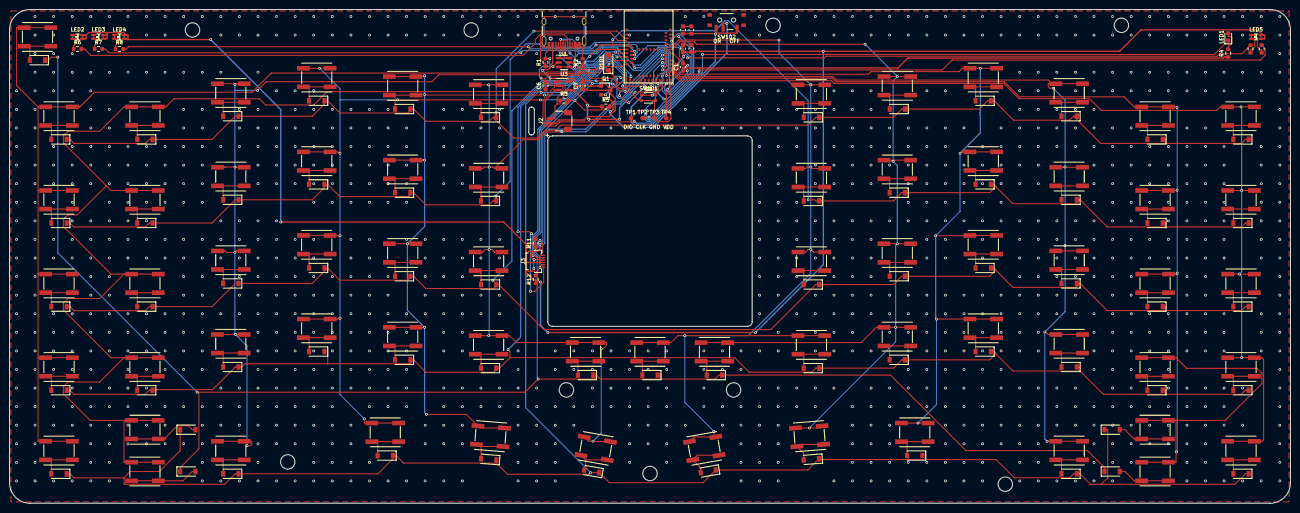
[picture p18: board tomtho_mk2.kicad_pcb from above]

Board: 2 copper layers, 275.8 x 106.3 mm, 179 parts (0 on the bottom side), 114 nets.

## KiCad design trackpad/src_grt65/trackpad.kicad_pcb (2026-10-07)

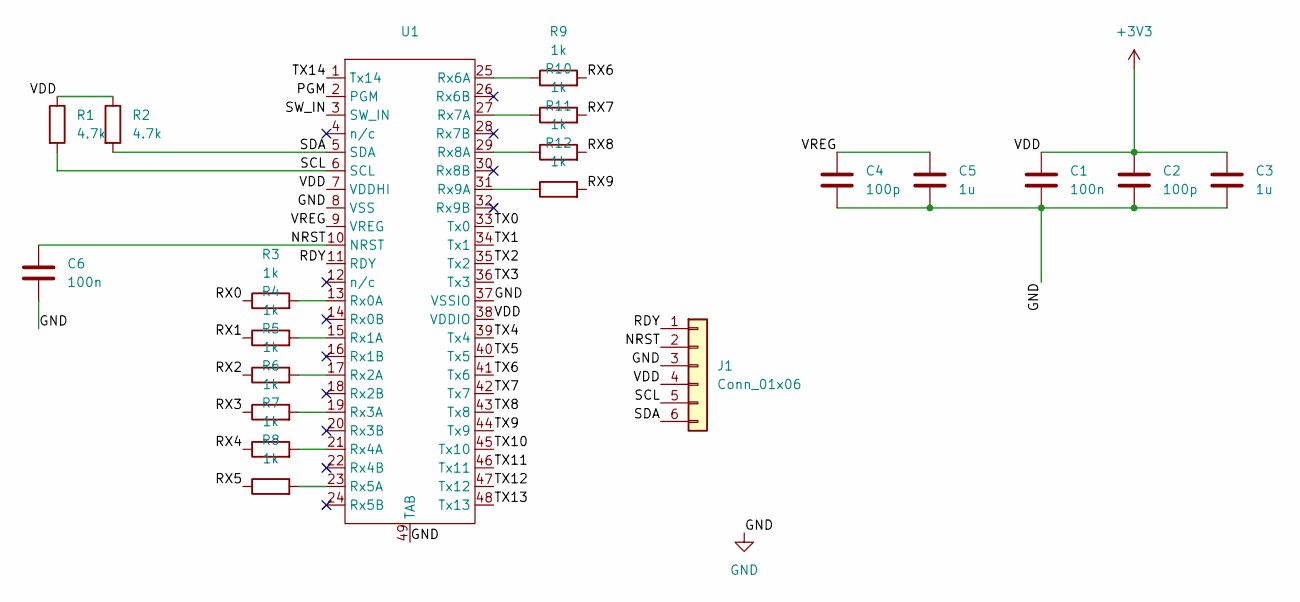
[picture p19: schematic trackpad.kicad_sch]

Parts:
C1, C6: 100n; C_0603_1608Metric
C2, C4: 100p; C_0603_1608Metric
C3, C5: 1u; C_0603_1608Metric
J1: Conn_01x06; Jushuo_AFC07-S06FCA-00_1x6-1MP_P0.50_Horizontal-JLC; LCSC Part # C11048
R1, R2: 4.7k; R_0603_1608Metric
R3, R4, R5, R6, R7, R8, R9, R10, R11, R12: 1k; R_0603_1608Metric
U1: QFN-48-1EP_7x7mm_P0.5mm_EP3.5x3.5mm

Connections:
+3V3: C1.1, C2.1, C3.1, J1.4, R1.1, R2.1, U1.7 (VDDHI), U1.38 (VDDIO)
/NRST: C6.1, J1.2, U1.10 (NRST)
/PGM: U1.2 (PGM)
/RDY: J1.1, U1.11 (RDY)
/RX0: R3.1
/RX1: R4.1
/RX2: R5.1
/RX3: R6.1
/RX4: R7.1
/RX5: R8.1
/RX6: R9.2
/RX7: R10.2
/RX8: R11.2
/RX9: R12.2
/SCL: J1.5, R1.2, U1.6 (SCL)
/SDA: J1.6, R2.2, U1.5 (SDA)
/SW_IN: U1.3 (SW_IN)
/TX0: U1.33 (Tx0)
/TX1: U1.34 (Tx1)
/TX2: U1.35 (Tx2)
/TX3: U1.36 (Tx3)
/TX4: U1.39 (Tx4)
/TX5: U1.40 (Tx5)
/TX6: U1.41 (Tx6)
/TX7: U1.42 (Tx7)
/TX8: U1.43 (Tx8)
/TX9: U1.44 (Tx9)
/TX10: U1.45 (Tx10)
/TX11: U1.46 (Tx11)
/TX12: U1.47 (Tx12)
/TX13: U1.48 (Tx13)
/TX14: U1.1 (Tx14)
/VREG: C4.1, C5.1, U1.9 (VREG)
GND: C1.2, C2.2, C3.2, C4.2, C5.2, C6.2, J1.3, U1.8 (VSS), U1.37 (VSSIO), U1.49 (TAB)
unnamed: R3.2, U1.13 (Rx0A)
unnamed: R4.2, U1.15 (Rx1A)
unnamed: R5.2, U1.17 (Rx2A)
unnamed: R6.2, U1.19 (Rx3A)
unnamed: R7.2, U1.21 (Rx4A)
unnamed: R8.2, U1.23 (Rx5A)
unnamed: R9.1, U1.25 (Rx6A)
unnamed: R10.1, U1.27 (Rx7A)
unnamed: R11.1, U1.29 (Rx8A)
unnamed: R12.1, U1.31 (Rx9A)

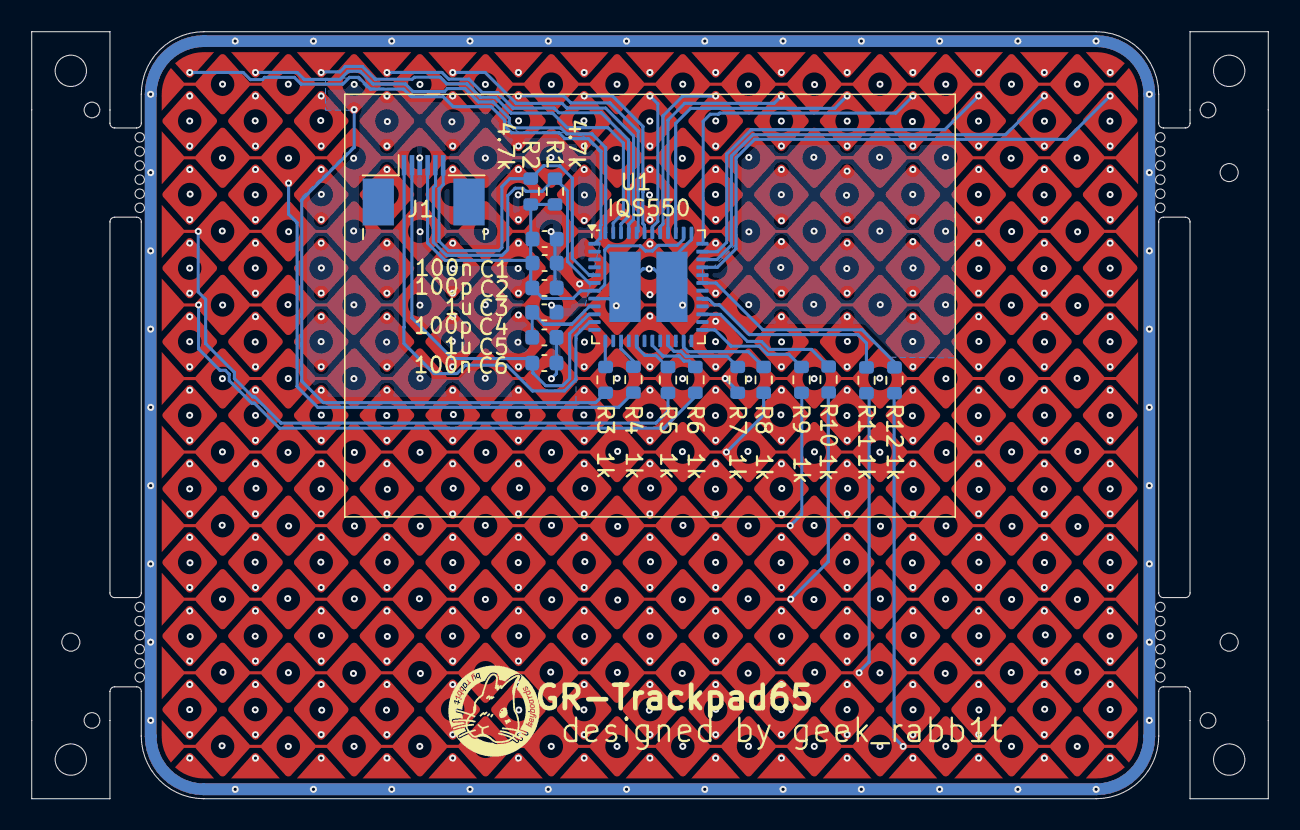
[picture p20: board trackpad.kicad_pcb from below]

Board: 4 copper layers, 79.0 x 49.0 mm, 20 parts (20 on the bottom side), 17 nets.

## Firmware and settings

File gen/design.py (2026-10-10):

"""tomtho-slim mk2 : 66 keys, roBa-style half stagger, centre Azoteq TPS43 trackpad module (FPC),
ALPS SKRA 6.2mm, 18.5x18 pitch, nRF52840 (Raytac MDBT50Q-1MV2) on board, LiPo + USB-C, ZMK.

Single source of truth for parts and nets.  Key positions come from ../layout_v20.json.
All coordinates: KiCad mm, y-down, origin = rear-left corner of the case outline.
"""
import json
import math
import os
from fplib import FP

HERE = os.path.dirname(os.path.abspath(__file__))
L = json.load(open(os.path.join(HERE, '..', 'layout_v20.json')))
W, H = L['outline']
BOARD = (0.6, 0.6, W - 0.6, H - 0.6)          # PCB = case outline minus 0.6 mm wall clearance
TP = L['trackpad']
FX0 = TP['free_area_x']                         # 114.0: left edge of the centre free area (fixed by the keys)

# ------------------------------------------------------------------ matrix (6 rows x 12 cols, COL2ROW)
MATRIX = {
    0: ['`', '1', '2', '3', '4', '5', '6', '7', '8', '9', '0', '-'],
    1: ['Tab', 'Q', 'W', 'E', 'R', 'T', 'Y', 'U', 'I', 'O', 'P', '['],
    2: ['Ctl', 'A', 'S', 'D', 'F', 'G', 'H', 'J', 'K', 'L', "'", ']'],
    3: ['⇧', 'Z', 'X', 'C', 'V', 'B', 'N', 'M', ',', '.', '/', 'Ent'],
    4: ['Ctrl', 'Fn', 'Alt', '変換 L6', 'Space L2', '無変換 L3', 'BS', 'Enter L1', 'Del', '←', '↑', '→'],
    5: ['BT 切替', 'Win', None, None, None, 'mL', 'mM', 'mR', None, None, '↓', None],
}
MOUSE = {'L': 'mL', 'M': 'mM', 'R': 'mR'}
NROWS, NCOLS = 6, 12


def key_name(k):
    return MOUSE[k['label']] if k['kind'] == 'mouse' else k['label']


def rot(x, y, a):
    a = math.radians(a)
    return x * math.cos(a) + y * math.sin(a), -x * math.sin(a) + y * math.cos(a)


PARTS = {}


def add(ref, fp, value, x, y, r, nets, sym, lcsc='', desc='', mpn='', bom=True, dnp=False):
    assert fp in FP, fp
    assert ref not in PARTS, f'duplicate reference {ref}'
    PARTS[ref] = dict(ref=ref, fp=fp, value=value, x=x, y=y, rot=r, nets=nets, sym=sym,
                      lcsc=lcsc, desc=desc, mpn=mpn, bom=bom, dnp=dnp)


# --- keys: SW n / D n, numbered in matrix order (row-major)
where = {}
for k in L['keys']:
    where[key_name(k)] = k
CELLS = []                      # (n, r, c, name)
n = 0
for r in range(NROWS):
    for c in range(NCOLS):
        name = MATRIX[r][c]
        if name is None:
            continue
        assert name in where, name
        n += 1
        CELLS.append((n, r, c, name))
        k = where[name]
        a = -k['rot_deg']                       # KiCad rotation is CCW-positive, layout is CW-positive (y-down)
        add(f'SW{n}', 'SW_ALPS_SKRA_6.2mm', 'SKRAAWE010', k['cx'], k['cy'], a,
            {'1': f'COL{c}', '2': f'K{r}_{c}'}, 'SW_Push', 'C202383',
            f'key "{name}" - ALPS SKRA 6.2mm tact', 'SKRAAWE010')
        if name in ('Fn', 'Win'):               # left stacked 0.5u keys: mirror of the arrows, diode towards Alt
            dx, dy, da = 9.25, 0.0, 0
        elif name in ('↑', '↓'):                  # stacked 0.5u keys: diode in the gap to the left (towards ←),
            dx, dy, da = -9.25, 0.0, 0          # clear of the ACC keycap legs (corner zones r 2 at +-7.55 / +-2.8)
        else:
            dx, dy = rot(0, 5.0, a)
            da = a + 180
        add(f'D{n}', 'D_SOD-123', '1N4148W', k['cx'] + dx, k['cy'] + dy, da,
            {'1': f'ROW{r}', '2': f'K{r}_{c}'}, 'D', 'C81598', 'Switching diode', '1N4148W')
assert n == len(L['keys']) == 66, n
NKEYS = n

# --- MCU module in the free area between "5" and "6", antenna at the rear edge
U1X = FX0 + 24.2            # 138.2: module centred in the free area between "5" and "6"
U1Y = 0.6 + 8.05                # antenna edge on the board's rear edge
MCU_PINS = {
    # outer pads: matrix
    '3': 'ROW0', '4': 'ROW1', '6': 'ROW2', '8': 'ROW3', '10': 'ROW4', '12': 'ROW5',
    '14': 'COL0', '16': 'COL1', '20': 'COL2', '22': 'COL3', '24': 'COL4', '26': 'COL5',
    '48': 'COL6', '46': 'COL7', '44': 'COL8', '41': 'COL9', '39': 'COL10', '37': 'COL11',
    # inner pads: LEDs (left) and trackpad (right)
    '5': 'LED_BT1', '7': 'LED_BT2', '9': 'LED_BT3', '11': 'LED_PWR_G', '13': 'LED_PWR_R',
    '36': 'TP_SDA', '38': 'TP_SCL', '42': 'TP_RDY', '43': 'TP_RST',
    # system
    '40': 'RESET', '51': 'SWDIO', '53': 'SWCLK', '35': 'USB_DP', '34': 'USB_DN',
    '28': 'VDD', '30': 'VDDH', '32': 'VBUS',
    '1': 'GND', '2': 'GND', '15': 'GND', '33': 'GND', '55': 'GND',
}
PIN_NAMES = {'1': 'GND', '2': 'GND', '3': 'P1.10', '4': 'P1.11', '5': 'P1.12', '6': 'P1.13', '7': 'P1.14',
             '8': 'P1.15', '9': 'P0.03/AIN1', '10': 'P0.29/AIN5', '11': 'P0.02/AIN0', '12': 'P0.31/AIN7',
             '13': 'P0.28/AIN4', '14': 'P0.30/AIN6', '15': 'GND', '16': 'P0.27', '17': 'P0.00/XL1',
             '18': 'P0.01/XL2', '19': 'P0.26', '20': 'P0.04/AIN2', '21': 'P0.05/AIN3', '22': 'P0.06',
             '23': 'P0.07', '24': 'P0.08', '25': 'P1.08', '26': 'P1.09', '27': 'P0.11', '28': 'VDD',
             '29': 'P0.12', '30': 'VDDH', '31': 'DCCH', '32': 'VBUS', '33': 'GND', '34': 'D-', '35': 'D+',
             '36': 'P0.14', '37': 'P0.13', '38': 'P0.16', '39': 'P0.15', '40': 'P0.18/RESET', '41': 'P0.17',
             '42': 'P0.19', '43': 'P0.21', '44': 'P0.20', '45': 'P0.23', '46': 'P0.22', '47': 'P1.00',
             '48': 'P0.24', '49': 'P0.25', '50': 'P1.02', '51': 'SWDIO', '52': 'P0.09/NFC1', '53': 'SWDCLK',
             '54': 'P0.10/NFC2', '55': 'GND', '56': 'P1.04', '57': 'P1.06', '58': 'P1.07', '59': 'P1.05',
             '60': 'P1.03', '61': 'P1.01'}
add('U1', 'Raytac_MDBT50Q', 'MDBT50Q-1MV2', U1X, U1Y, 0, dict(MCU_PINS), 'MDBT50Q', 'C5118826',
    'nRF52840 BLE module, chip antenna, TELEC certified', 'MDBT50Q-1MV2')

FX = FX0                        # 114.0  free area: x 113.5..163.5, y 0.6..28.2 (trackpad starts at 28.7)
# module decoupling, right of the module
add('C2', 'C_0603', '10uF', U1X + 7.4, 5.0, 90, {'1': 'VDDH', '2': 'GND'}, 'C', 'C19702', '10V X5R', 'CL10A106KP8NNNC')
add('C3', 'C_0603', '100nF', U1X + 9.2, 5.0, 90, {'1': 'VDDH', '2': 'GND'}, 'C', 'C14663', '50V X7R', 'CC0603KRX7R9BB104')
add('C4', 'C_0603', '4.7uF', U1X + 7.4, 9.0, 90, {'1': 'VDD', '2': 'GND'}, 'C', 'C19666', '16V X5R', 'CL10A475KO8NNNC')
add('C5', 'C_0603', '100nF', U1X + 9.2, 9.0, 90, {'1': 'VDD', '2': 'GND'}, 'C', 'C14663', '50V X7R', 'CC0603KRX7R9BB104')
add('C1', 'C_0603', '4.7uF', U1X + 7.4, 13.0, 90, {'1': 'VBUS', '2': 'GND'}, 'C', 'C19666', '16V X5R', 'CL10A475KO8NNNC')

# reset + SWD pads, below the module
add('SW101', 'SW_TS-1928-B', 'RESET', U1X, 19.6, 0, {'1': 'RESET', '2': 'GND'}, 'SW_Push', 'C1121891',
    'Reset (double-tap = UF2 bootloader)', 'TS-1928-B')
for i, net in enumerate(['SWDIO', 'SWCLK', 'GND', 'VDD']):
    add(f'TP{i + 1}', 'TestPoint_Pad_D1.0mm', net, U1X - 3.81 + i * 2.54, 24.0, 0, {'1': net}, 'TestPoint', bom=False,
        desc='SWD pad for first bootloader flash')

# USB-C (top mount, rear edge) + ESD
add('J1', 'USB_C_HRO_TYPE-C-31-M-12', 'USB-C', FX + 6.0, 0.6 + 3.65, 180,
    {'A1': 'GND', 'B1': 'GND', 'A12': 'GND', 'B12': 'GND', 'A4': 'VBUS', 'B4': 'VBUS', 'A9': 'VBUS', 'B9': 'VBUS',
     'A5': 'CC1', 'B5': 'CC2', 'A6': 'USB_DP', 'B6': 'USB_DP', 'A7': 'USB_DN', 'B7': 'USB_DN', 'S1': 'GND'},
    'USB_C', 'C165948', 'USB2.0 Type-C receptacle, top mount (sits in the free area under the case top)', 'TYPE-C-31-M-12')
add('R1', 'R_0603', '5.1k', FX + 2.0, 12.0, 90, {'1': 'CC1', '2': 'GND'}, 'R', 'C23186', 'CC pull-down', '0603WAF5101T5E')
add('R2', 'R_0603', '5.1k', FX + 10.0, 12.0, 90, {'1': 'CC2', '2': 'GND'}, 'R', 'C23186', 'CC pull-down', '0603WAF5101T5E')
add('U2', 'SOT-23-6', 'USBLC6-2SC6', FX + 6.0, 12.0, 0,
    {'1': 'USB_DP', '6': 'USB_DP', '3': 'USB_DN', '4': 'USB_DN', '5': 'VBUS', '2': 'GND'},
    'USBLC6', 'C7519', 'USB ESD protection', 'USBLC6-2SC6')

# charger (MCP73831, 100 mA)
add('U3', 'SOT-23-5', 'MCP73831', FX + 6.0, 17.0, 0,
    {'1': 'CHG_STAT', '2': 'GND', '3': 'VBAT', '4': 'VBUS', '5': 'PROG'}, 'MCP73831', 'C424093',
    'Li-Po charger 4.2V', 'MCP73831T-2ACI/OT')
add('C6', 'C_0603', '4.7uF', FX + 2.0, 17.0, 90, {'1': 'VBUS', '2': 'GND'}, 'C', 'C19666', '16V X5R', 'CL10A475KO8NNNC')
add('C7', 'C_0603', '4.7uF', FX + 10.0, 17.0, 90, {'1': 'VBAT', '2': 'GND'}, 'C', 'C19666', '16V X5R', 'CL10A475KO8NNNC')
add('R3', 'R_0603', '4.7k', FX + 6.0, 20.2, 0, {'1': 'PROG', '2': 'GND'}, 'R', 'C23162', 'Ichg = 1000V/4.7k = 213mA (0.2-0.5C for an 800-1000 mAh cell)',
    '0603WAF4701T5E')

# load-sharing power path (Microchip AN1149 style)
add('D101', 'D_SOD-123', 'B5819W', FX + 15.5, 12.0, 90, {'1': 'VSYS', '2': 'VBUS'}, 'D_Schottky', 'C8598',
    'VBUS -> VSYS', 'B5819W SL')
add('Q1', 'SOT-23', 'AO3401A', FX + 15.0, 18.0, 0, {'1': 'VBUS', '2': 'VSYS', '3': 'VBAT'}, 'PMOS', 'C15127',
    'Battery -> VSYS when no USB', 'AO3401A')
add('R5', 'R_0603', '100k', FX + 15.0, 21.5, 0, {'1': 'VBUS', '2': 'GND'}, 'R', 'C25803', 'Q1 gate pull-down',
    '0603WAF1003T5E')
# power switch (rear edge, right of the module) + battery connector (LiPo sits under the PCB)
add('SW102', 'SW_SPDT_PCM12', 'POWER', FX + 41.0, 0.6 + 2.6, 180, {'1': 'VDDH', '2': 'VSYS'},
    'SW_SPDT', 'C221841', 'Power slide switch (pin3 = OFF, open)', 'PCM12SMTR')
add('J2', 'JST_SH_SM02B-SRSS-TB', 'BATTERY', FX + 5.0, 24.6, 90, {'1': 'VBAT', '2': 'GND'}, 'Conn_02', 'C160402',
    'LiPo 1S (protected cell), check polarity!', 'SM02B-SRSS-TB(LF)(SN)')

# charge LED (red, VBUS powered, on while charging) - top right, next to the power LED
add('R4', 'R_0603', '1k', W - 14.0, 10.0, 90, {'1': 'VBUS', '2': 'LED_CHG_A'}, 'R', 'C21190', 'LED resistor',
    '0603WAF1001T5E')
add('LED1', 'LED_0603', 'RED', W - 14.0, 6.5, 90, {'1': 'CHG_STAT', '2': 'LED_CHG_A'}, 'LED', 'C2286',
    'Charge indicator (on while charging)', 'KT-0603R')

# indicator LEDs: bicolour XL-2012SURSYGC (1=R- 2=R+ 3=YG- 4=YG+), both anodes on VDD, cathodes sunk by GPIO via 1k
LEDS = L['leds']
_led = {e['name']: e for e in LEDS}
LED_RES = 'C21190'
for i in range(3):
    e = _led[f'BT{i + 1}']
    add(f'LED{2 + i}', 'LED_XL-2012_Bicolor', 'XL-2012SURSYGC', e['cx'], e['cy'], 0,
        {'2': 'VDD', '4': 'VDD', '3': f'LED_BT{i + 1}_K'}, 'LED_Dual_CA', 'C965847',
        f'BT{i + 1} profile LED (yellow-green die used, red unused)', 'XL-2012SURSYGC')
    add(f'R{6 + i}', 'R_0603', '1k', e['cx'], e['cy'] + 2.6, 0, {'1': f'LED_BT{i + 1}_K', '2': f'LED_BT{i + 1}'},
        'R', LED_RES, 'LED current ~1 mA', '0603WAF1001T5E')
e = _led['PWR']
add('LED5', 'LED_XL-2012_Bicolor', 'XL-2012SURSYGC', e['cx'], e['cy'], 0,
    {'2': 'VDD', '4': 'VDD', '1': 'LED_PWR_RK', '3': 'LED_PWR_GK'}, 'LED_Dual_CA', 'C965847',
    'Power / battery LED (green = OK, red = <20 %)', 'XL-2012SURSYGC')
add('R9', 'R_0603', '1k', e['cx'] - 1.2, e['cy'] + 2.6, 90, {'1': 'LED_PWR_GK', '2': 'LED_PWR_G'}, 'R', LED_RES,
    'LED current ~1 mA', '0603WAF1001T5E')
add('R10', 'R_0603', '1k', e['cx'] + 1.2, e['cy'] + 2.6, 90, {'1': 'LED_PWR_RK', '2': 'LED_PWR_R'}, 'R', LED_RES,
    'LED current ~1 mA', '0603WAF1001T5E')

# trackpad module connector (FPC 6P 0.5 mm) + I2C pull-ups
# Azoteq TPS43-201A-S (43 x 40, 1.0 t PCB, IQS572, ZIF J1 on its underside) is stuck with its own 3M 468 adhesive to
# the underside of the case-top window.  Its underside parts hang into a cut-out of this board, so the pad surface can
# sit flush with the case top.  J3 is just left of the cut-out.  TPS43 J1 pinout (datasheet table 2.1):
# 1 RDY, 2 NRST, 3 GND, 4 VDDHI, 5 SCL, 6 SDA  -> J3 uses the same numbering.  The FFC type (A = same side /
# B = opposite sides) is chosen once the position and contact side of the module's ZIF are measured: pin 1 must
# reach pin 1 (a mirrored cable swaps GND and VDD).
TP_CUT = (TP['x'] - 0.5, TP['y'] - 0.5, TP['x'] + TP['w'] + 0.5, TP['y'] + TP['h'] + 0.5)
# J3 sits level with the centre of the G key: the ACC keycap legs of T / G / B (corner zones, r 2) leave a free band there
TPJ = (TP_CUT[0], next(k['cy'] for k in L['keys'] if k['label'] == 'G'))
add('J3', 'FPC_0.5mm_6P_HC', 'TRACKPAD', TP_CUT[0] - 2.3, TPJ[1], 90,
    {'1': 'TP_RDY', '2': 'TP_RST', '3': 'GND', '4': 'VDD', '5': 'TP_SCL', '6': 'TP_SDA', 'MP': 'GND'},
    'Conn_FPC6', 'C5213729', 'To Azoteq TPS43 trackpad module (FFC 6P 0.5 mm)', 'HC-FPC-05-10-6RLTAG')
add('R11', 'R_0603', '4.7k', TP_CUT[0] - 2.6, TPJ[1] - 3.9, 90, {'1': 'VDD', '2': 'TP_SDA'}, 'R', 'C23162',
    'I2C pull-up', '0603WAF4701T5E')
add('R12', 'R_0603', '4.7k', TP_CUT[0] - 2.6, TPJ[1] + 3.9, 90, {'1': 'VDD', '2': 'TP_SCL'}, 'R', 'C23162',
    'I2C pull-up', '0603WAF4701T5E')

# case screws (M2, from below, into bosses of the top frame): rear strip and front edge, where the ACC keycap holes
# leave >= 2.9 mm free.  None inside the key field: the plate webs between keycaps are only 2 mm wide.
# Tadpole Pin D3.0 mounts (GEONWORKS, silicone): the rod (d3.0) goes up through the PCB into a blind hole in the top
# frame, the bulge sits under the PCB in a cup on the bottom plate.  4 rear, 2 front, 3 centre (either side below the
# trackpad, and between the inner thumbs).  Spots chosen clear of keys (+2.9), parts (+2.0) and tracks (1.95 from the hole centre).
SCREWS = [(40.0, 5.0), (100.0, 5.0), (165.0, 4.0), (240.0, 4.0),
          (60.5, 98.0), (215.0, 102.8), (120.5, 82.5), (156.5, 82.5),
          (138.5, 100.5)]                  # 9th (v22): front centre between the inner thumb keys (1 of the 10 kept spare)
for i, (x, y) in enumerate(SCREWS):
    add(f'H{i + 1}', 'Tadpole_D3.0_NPTH', 'Tadpole', x, y, 0, {}, 'MountingHole', bom=False)

POWER_NETS = {'VBUS', 'VSYS', 'VBAT', 'VDDH', 'VDD'}

# ------------------------------------------------------------------ board-level geometry for the PCB writer / router
VIA = (0.6, 0.3)
CORNER_R = 4.4
ANT_KEEPOUT = (U1X - 6.2, BOARD[1], U1X + 6.2, U1Y - 3.95)           # no copper on either layer
MODULE_FCU_KEEPOUT = (U1X - 2.5, U1Y - 3.5, U1X + 2.5, U1Y + 5.6)     # no F.Cu tracks under the module centre
BATTERY_AREA = (22.0, 34.0, 92.0, 74.0)                                # LiPo under the PCB (B side), 70 x 40 max
SLOT_R = 1.0                                                            # inner corner radius of the cut-outs
SLOTS = [(112.4, 21.6, 113.6, 27.6), TP_CUT]                            # battery lead pass-through, trackpad cut-out
SILK_RECTS = [('B.SilkS',) + BATTERY_AREA]
SILK_TEXTS = [
    ('B.SilkS', 57.0, 54.0, 'LiPo 1S  (<= 3.0 t x 40 x 70)', 1.5),
    ('B.SilkS', 57.0, 57.5, 'lead -> slot -> J2 (pin1 = +)', 1.0),
    ('B.SilkS', 57.0, 62.0, 'JLCJLCJLCJLC', 1.0),           # JLC order number goes here (hidden under the LiPo)
    ('B.SilkS', 200.0, 77.5, 'Ashiyu', 3.0),
    ('B.SilkS', 200.0, 81.5, 'Designed by tommys079', 1.5),
    ('B.SilkS', 200.0, 84.3, 'Inspired by ClickBoard (Salicylic_acid3)', 1.0),
    ('F.SilkS', U1X - 3.81 + 3.81, 25.9, 'DIO CLK GND VDD', 0.8),
    ('F.SilkS', FX + 41.0, 7.4, 'ON   OFF', 0.8),
    ('F.SilkS', FX + 2.4, 27.6, '+', 1.0),
]
# designer's logo (bitmap2component footprint, F.SilkS polygons) on the back silkscreen, mirrored to read from below
LOGO = dict(file='lib/tommys079_logo.kicad_mod', x=200.0, y=52.0, scale=0.8, layer='B.SilkS')
TRACKS, VIAS = [], []
for _r in ('C2', 'C3', 'C4', 'C5', 'R9', 'R10', 'U2') + tuple(f'H{i + 1}' for i in range(len(SCREWS))):
    PARTS[_r]['ref_fab'] = True                     # crowded spots: reference on F.Fab instead of silk

# inner-row module pads cannot escape between the outer pads (0.4 mm gaps): short F.Cu stub inward to a via
ESC_PADS = ['5', '7', '9', '11', '13', '36', '38', '40', '42', '43']


def escapes():
    t, v = [], []
    for num in ESC_PADS:
        net = MCU_PINS[num]
        X, Y = next((h[3], h[4]) for h in pad_world(PARTS['U1']) if h[0] == num)
        vx = X + (0.75 if X < U1X else -0.75)
        t.append(('F.Cu', X, Y, vx, Y, 0.2, net))
        v.append((vx, Y, net))
    # USB-C: join A7 and B7 (D-) with a short F.Cu bridge on the edge side of the pad row, over A6 (D+).
    # The autorouter does not always find this one on its own.
    pw = {h[0]: (h[3], h[4]) for h in pad_world(PARTS['J1'])}
    (ax, ay), (bx, by) = pw['A7'], pw['B7']
    yb = ay - 0.977
    t += [('F.Cu', ax, ay, ax, yb, 0.2, 'USB_DN'), ('F.Cu', bx, by, bx, yb, 0.2, 'USB_DN'),
          ('F.Cu', ax, yb, bx, yb, 0.2, 'USB_DN')]
    return t, v


def pad_world(part):
    fp = FP[part['fp']]
    for (num, kind, shape, x, y, w, h, drill) in fp['pads']:
        dx, dy = rot(x, y, part['rot'])
        W_, H_ = (h, w) if part['rot'] % 180 == 90 else (w, h)
        net = part['nets'].get(num, '') if num else ''
        yield num, kind, shape, part['x'] + dx, part['y'] + dy, W_, H_, drill, net


def all_nets():
    s = set()
    for p in PARTS.values():
        s.update(v for v in p['nets'].values() if v)
    return sorted(s)


if __name__ == '__main__':
    print(len(PARTS), 'parts', len(all_nets()), 'nets', NKEYS, 'keys')
    used = [v for v in MCU_PINS.values() if v not in ('GND',)]
    print('MCU pins used:', len(MCU_PINS), 'GPIO signals:', sum(1 for v in MCU_PINS.values()
          if v.startswith(('ROW', 'COL', 'LED', 'TP_'))))

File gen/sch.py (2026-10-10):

"""Schematic generator (KiCad 9/10 s-expression).  Netlist comes from design.PARTS, so it is
identical to the PCB by construction; symbol <-> footprint linkage uses the same UUIDs."""
import design as D
from pcbio import U, q, f, PROJECT, LIB, ROOT_UUID, REPO

FONT = '(effects (font (size 1.27 1.27)))'
FONT_H = '(effects (font (size 1.27 1.27)) (hide yes))'


def fnt(j=None, hide=False, size=1.27):
    s = f'(effects (font (size {f(size)} {f(size)}))'
    if j:
        s += f' (justify {j})'
    if hide:
        s += ' (hide yes)'
    return s + ')'


# ------------------------------------------------------------------ symbol library
SYMS = {}


def sym(name, pins, graphics, ref, desc, show_num=True, show_names=True, power=False, props=None):
    SYMS[name] = dict(pins=pins, graphics=graphics, ref=ref, desc=desc, show_num=show_num,
                      show_names=show_names, power=power, props=props or {})


def rect(x1, y1, x2, y2, fill='background'):
    return f'(rectangle (start {f(x1)} {f(y1)}) (end {f(x2)} {f(y2)}) (stroke (width 0.254) (type default)) (fill (type {fill})))'


def poly(pts, fill='none', w=0.254):
    p = ' '.join(f'(xy {f(x)} {f(y)})' for x, y in pts)
    return f'(polyline (pts {p}) (stroke (width {f(w)}) (type default)) (fill (type {fill})))'


def circ(x, y, r, fill='none'):
    return f'(circle (center {f(x)} {f(y)}) (radius {f(r)}) (stroke (width 0.254) (type default)) (fill (type {fill})))'


# pins: (num, name, x, y, angle, length, etype)
sym('R', [('1', '~', 0, 3.81, 270, 1.27, 'passive'), ('2', '~', 0, -3.81, 90, 1.27, 'passive')],
    [rect(-1.016, -2.54, 1.016, 2.54, 'none')], 'R', 'Resistor', show_num=False, show_names=False)
sym('C', [('1', '~', 0, 3.81, 270, 2.794, 'passive'), ('2', '~', 0, -3.81, 90, 2.794, 'passive')],
    [poly([(-2.032, 0.762), (2.032, 0.762)], w=0.508), poly([(-2.032, -0.762), (2.032, -0.762)], w=0.508)],
    'C', 'Capacitor', show_num=False, show_names=False)
_dio = [poly([(-1.27, 1.27), (1.27, 1.27), (0, -1.27), (-1.27, 1.27)], 'none'), poly([(-1.27, -1.27), (1.27, -1.27)])]
sym('D', [('1', 'K', 0, -3.81, 90, 2.54, 'passive'), ('2', 'A', 0, 3.81, 270, 2.54, 'passive')],
    _dio, 'D', 'Diode (pin1=K)', show_num=False, show_names=False)
sym('D_Schottky', [('1', 'K', 0, -3.81, 90, 2.54, 'passive'), ('2', 'A', 0, 3.81, 270, 2.54, 'passive')],
    _dio + [poly([(-1.27, -1.27), (-1.27, -0.762)]), poly([(1.27, -1.27), (1.27, -1.778)])],
    'D', 'Schottky diode (pin1=K)', show_num=False, show_names=False)
sym('LED', [('1', 'K', 0, -3.81, 90, 2.54, 'passive'), ('2', 'A', 0, 3.81, 270, 2.54, 'passive')],
    _dio + [poly([(1.778, 0.508), (2.794, -0.508)]), poly([(2.286, 1.016), (3.302, 0)])],
    'LED', 'LED (pin1=K)', show_num=False, show_names=False)
sym('SW_Push', [('1', '1', -5.08, 0, 0, 2.54, 'passive'), ('2', '2', 5.08, 0, 180, 2.54, 'passive')],
    [circ(-2.032, 0, 0.508), circ(2.032, 0, 0.508), poly([(-2.54, 1.27), (2.54, 1.27)]),
     poly([(0, 1.27), (0, 3.048)])], 'SW', 'Push switch', show_num=False, show_names=False)
sym('SW_SPDT', [('2', 'C', -5.08, 0, 0, 2.54, 'passive'), ('1', 'A', 5.08, 2.54, 180, 2.54, 'passive'),
                ('3', 'B', 5.08, -2.54, 180, 2.54, 'passive')],
    [circ(-2.032, 0, 0.508), circ(2.032, 2.54, 0.508), circ(2.032, -2.54, 0.508), poly([(-1.524, 0.254), (1.778, 2.032)])],
    'SW', 'SPDT slide switch', show_names=False)
sym('PMOS', [('1', 'G', -5.08, 0, 0, 2.54, 'passive'), ('2', 'S', 2.54, 5.08, 270, 2.54, 'passive'),
             ('3', 'D', 2.54, -5.08, 90, 2.54, 'passive')],
    [poly([(-1.016, 1.778), (-1.016, -1.778)]), poly([(-2.54, 0), (-1.016, 0)]),
     poly([(-0.508, 1.778), (-0.508, -1.778)]), poly([(-0.508, 1.27), (2.54, 1.27), (2.54, 2.54)]),
     poly([(-0.508, -1.27), (2.54, -1.27), (2.54, -2.54)]), circ(0.5, 0, 2.8)],
    'Q', 'P-channel MOSFET (1=G 2=S 3=D)')
sym('TestPoint', [('1', '1', 0, 0, 90, 0, 'passive')], [circ(0, 1.27, 0.762)], 'TP', 'Test pad',
    show_num=False, show_names=False)
sym('MountingHole', [], [circ(0, 0, 1.27), circ(0, 0, 0.635)], 'H', 'Mounting hole', show_num=False)
sym('GND', [('1', 'GND', 0, 0, 270, 0, 'power_in')],
    [poly([(0, 0), (0, -1.27), (1.27, -1.27), (0, -2.54), (-1.27, -1.27), (0, -1.27)])], '#PWR', 'Ground',
    show_num=False, show_names=False, power=True)
sym('PWR_FLAG', [('1', 'pwr', 0, 0, 90, 0, 'power_out')],
    [poly([(0, 0), (0, 1.27), (-1.016, 1.905), (0, 2.54), (1.016, 1.905), (0, 1.27)])], '#FLG', 'Power flag',
    show_num=False, show_names=False, power=False)


def box(name, left, right, w, ref, desc, top=(), bottom=()):
    n = max(len(left), len(right), 1)
    h = n * 2.54
    pins = []
    for side, lst in (('L', left), ('R', right)):
        for k, (num, nm) in enumerate(lst):
            y = (n - 1) * 2.54 / 2 - k * 2.54
            if side == 'L':
                pins.append((num, nm, -w / 2 - 2.54, y, 0, 2.54, 'passive'))
            else:
                pins.append((num, nm, w / 2 + 2.54, y, 180, 2.54, 'passive'))
    sym(name, pins, [rect(-w / 2, h / 2 + 1.27, w / 2, -h / 2 - 1.27)], ref, desc)


# MDBT50Q: system pins left, GPIO right
_sys = ['28', '30', '31', '32', '35', '34', '51', '53', '40', '17', '18', '52', '54', '1', '2', '15', '33', '55']
_gpio = [p for p in sorted(D.PIN_NAMES, key=int) if p not in _sys]
_gpio.sort(key=lambda p: (D.PIN_NAMES[p].split('/')[0][:2], int(D.PIN_NAMES[p].split('/')[0].split('.')[1])))
box('MDBT50Q', [(p, D.PIN_NAMES[p]) for p in _sys], [(p, D.PIN_NAMES[p]) for p in _gpio], 20.32, 'U',
    'Raytac MDBT50Q-1MV2 nRF52840 module')
box('MCP73831', [('4', 'VDD'), ('1', 'STAT'), ('5', 'PROG')], [('3', 'VBAT'), ('2', 'VSS')], 12.7, 'U',
    'Li-Po charger')
box('USBLC6', [('1', 'I/O1'), ('3', 'I/O2'), ('5', 'VBUS')], [('6', 'I/O1'), ('4', 'I/O2'), ('2', 'GND')], 12.7, 'U',
    'USB ESD')
box('USB_C', [('A4', 'VBUS'), ('A9', 'VBUS'), ('B4', 'VBUS'), ('B9', 'VBUS'), ('A5', 'CC1'), ('B5', 'CC2'),
              ('A6', 'D+'), ('B6', 'D+'), ('A7', 'D-'), ('B7', 'D-'), ('A8', 'SBU1'), ('B8', 'SBU2')],
    [('A1', 'GND'), ('A12', 'GND'), ('B1', 'GND'), ('B12', 'GND'), ('S1', 'SHIELD')], 12.7, 'J',
    'USB 2.0 Type-C receptacle')
box('Conn_02', [('1', 'BAT+'), ('2', 'BAT-')], [], 7.62, 'J', 'JST SH 2-pin')
box('LED_Dual_CA', [('2', 'R+'), ('4', 'YG+')], [('1', 'R-'), ('3', 'YG-')], 10.16, 'LED',
    'Bicolour LED, common anode (XL-2012SURSYGC)')
box('Conn_FPC6', [('1', 'RDY'), ('2', 'RST'), ('3', 'GND'), ('4', 'VDD'), ('5', 'SCL'), ('6', 'SDA')],
    [('MP', 'MP')], 10.16, 'J', 'FPC 6P 0.5 mm')
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

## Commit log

2026-10-07 mk2: freeze layout v19 (JSON) and 1:1 A4 print sheet
    Claude-Session: https://claude.ai/code/session_014QKLhpB6tKWk1p8Y7v384p
2026-10-07 mk2: README with settled spec, matrix/GPIO plan and board split
    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
2026-10-07 mk2: trackpad plan B (consigned IQS550), bicolour LED part, gesture notes
    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
2026-10-07 mk2: schematic (65-key wired matrix grid, MCU, power, LEDs, trackpad FPC) + CI ERC
    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
    [tomtho_mk2.kicad_sch]
2026-10-07 mk2: project file and footprint library so ERC resolves libraries
    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
2026-10-07 mk2: schematic text layout fixes
    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
    [tomtho_mk2.kicad_sch]
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2026-10-07 mk2: PCB placement (all 173 parts, 0 courtyard overlaps), real LED pin map, top-mount USB-C, local KiCad DRC + Freerouting pipeline
    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
    [tomtho_mk2.kicad_pcb, tomtho_mk2.kicad_sch]
2026-10-07 mk2: routed PCB (local KiCad 10 DRC: 0 violations, 0 unconnected, parity 0), JLC BOM/CPL, CI DRC + gerbers for mk2
    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
    [tomtho_mk2.kicad_pcb, tomtho_mk2_BOM.csv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]
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2026-10-07 mk2: trackpad board derived from GR-Trackpad65 (10Tx x 10Rx, 49x43, DRC clean); main board gets a trackpad cut-out, J3 beside it (DRC 0/0/0)
    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
    [tomtho_mk2.kicad_pcb, tomtho_mk2.kicad_sch, tomtho_mk2_trackpad.kicad_pcb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]
2026-10-07 mk2: trackpad -> Azoteq TPS43-201A-S (43x40); cut-out 44x41, J3 pinout per TPS43 J1; keys unchanged; DRC 0/0/0
    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
    [tomtho_mk2.kicad_pcb, tomtho_mk2.kicad_sch, tomtho_mk2_BOM.csv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]
2026-10-07 mk2: fetch every BOM part from LCSC/EasyEDA (for the JLC rotation check)
    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
2026-10-07 mk2 board check: JLC CPL in Gerber coordinates with per-footprint rotation/origin offsets (verified pad-on-pad against LCSC footprints), charge current 210 mA, README notes (STAT, REGOUT0, battery po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
    [tomtho_mk2.kicad_pcb, tomtho_mk2.kicad_sch, tomtho_mk2_BOM.csv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]
2026-10-07 mk2 case: CI CadQuery workflow, measure ACC keycaps + ClickBoard Tenkey reference (not stored)
    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
2026-10-07 mk2 case: measure part heights from the LCSC STEP models
    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
2026-10-07 mk2: case v1 (top frame + bottom plate + 0.5u x 0.5u flange cap) in CadQuery; PCB: 11 case screws in rear strip / front edge, arrow diodes and J3 moved clear of ACC keycap legs, USB D- bridge protect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
    [tomtho_mk2.kicad_pcb, tomtho_mk2.kicad_sch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]
2026-10-07 mk2 case: flange cap for 0.5u x 0.5u keys (plate thinned around them), interference checks + section views in CI
    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
2026-10-07 mk2 case: fix section plots, part heights from STEP, wider power-switch slot, flange cap clearance
    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
2026-10-08 mk2 case: trackpad edge groove, MJF clearance variant, 1.4 mm posts, README
    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
2026-10-08 mk2 case: cross ribs under the trackpad area; case preview images
    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
2026-10-08 mk2 case: resin chosen - thicker bosses (5.2) / 1.7 pilot, order guide for SLA resin
    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
2026-10-08 mk2: PCB 3D renders, keymap notes based on tomtho default keymap
    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
2026-10-08 mk2 case: 0.5u keycaps x6 on a sprue (JLC3DP minimum part size)
    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
2026-10-08 mk2: keycap STEP/STL per size (from ACC, CC BY-NC 4.0) + print sprues
    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
2026-10-08 mk2 case: rounded lead-in corners; test how round keycap holes can be
    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
2026-10-08 mk2 case: rounder keycap-hole corners (r 1.8; ACC caps clear up to r 2.0 incl. 0.1 mm play), 0.5u cap corners to match
    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
2026-10-08 mk2 case: PORON 3 mm template for the bottom-plate pockets (DXF + 1:1 A4 PDF)
    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
2026-10-08 mk2 case: PORON template via raster + erosion (all pockets, not only closed cells)
    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
2026-10-08 mk2: 1:1 paper test - current layout vs halves splayed 6 deg (A4 x2 / A3)
    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
2026-10-08 mk2: thumb options (1.25u / 1u at 1.1u pitch / 1u)
    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
2026-10-08 mk2 v21: column stagger 0.75 x roBa, thumbs 1u / 1.25u (Space, Enter) / 1u at 1.1u pitch, L/M/R 2.5 mm under the trackpad; PCB re-placed and re-routed, DRC 0/0/0
    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
    [tomtho_mk2.kicad_pcb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]
2026-10-08 mk2 case: finger-pressable reset plunger instead of the pin hole
    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
2026-10-08 mk2 case: reset plunger stem 2.0 -> 3.0 mm to tolerate misalignment
    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
2026-10-08 mk2 keycaps: domed thumb caps (ACC with dish filled, 0.4 mm ellipsoid dome, same peak height)
    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
2026-10-08 mk2 docs: domed thumb caps (printed), ACC purchase list without thumbs
    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
2026-10-08 mk2 case: round the 0.5u x 0.5u cap flange corners (r2.5, even overlap with the hole)
    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
2026-10-08 mk2 case: 0.5u cap flange really rounded (r2.5) - the fillet had not been applied
    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
2026-10-08 mk2 keycaps: thumb caps raised 0.3 mm (dome edges level with other rims)
    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
2026-10-09 mk2 check_case: pressed caps checked against switch bodies (own and neighbours); small-key clearance report
    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
2026-10-09 mk2 PCB: tommys079 logo + 'Designed by tommys079' on the back silkscreen (DRC 0/0/0)
    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
    [tomtho_mk2.kicad_pcb]
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2026-10-09 mk2: named Ashiyu - back silkscreen title + ClickBoard credit (DRC 0/0/0)
    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
    [tomtho_mk2.kicad_pcb]
2026-10-09 Ashiyu: name in KiCad title blocks, READMEs and ORDER (DRC 0/0/0, parity 0)
    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
    [tomtho_mk2.kicad_pcb, tomtho_mk2.kicad_sch]
2026-10-09 Ashiyu PCB: drop the parts line and the JLC order-number marker from the back silkscreen (DRC 0/0/0)
    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
    [tomtho_mk2.kicad_pcb]
2026-10-09 Ashiyu PCB: JLC order-number marker moved under the LiPo (back side, hidden)
    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
    [tomtho_mk2.kicad_pcb]
2026-10-09 Ashiyu PCB: rounded inside corners (r1.0) on the trackpad cut-out and battery-lead slot (DRC 0/0/0)
    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
    [tomtho_mk2.kicad_pcb]
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2026-10-09 Ashiyu case: snap-fit tabs (8: front 4, sides 2+2) with grooves; front/side walls 1.5 off the PCB with locating ribs; screws kept; snap test coupon
    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
2026-10-09 Revert the snap-fit tabs commit (not requested in this conversation); keep screws only
    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
2026-10-09 Ashiyu: screwless case - skirt down to the desk, bottom tray inside with 8 hidden spring clips; PCB floats on 8 Tadpole D3.0 pins (4 rear, 2 front, 2 centre); PCB holes d3.1 (DRC 0/0/0)
    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
    [tomtho_mk2.kicad_pcb, tomtho_mk2.kicad_sch]
2026-10-10 Ashiyu v22: lower-left Ctrl 1u / Fn+Win 0.5u stacked / Alt 1u (66 keys, Win on ROW5 COL1); 9th Tadpole pin (front centre); trackpad without cover plate (module touched directly through a 41x38 window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
    Claude-Session: https://claude.ai/code/session_01Rq3DZsqPhBbL1FAX1XrxAC
    [tomtho_mk2.kicad_pcb, tomtho_mk2.kicad_sch, tomtho_mk2_BOM.csv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]
2026-10-10 PCB: drop 2 unused escape vias (LED_BT1, LED_PWR_R) flagged as via_dangling by DRC
    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
    [tomtho_mk2.kicad_pcb]
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2026-10-10 ORDER: v22 keycap counts; HANDOFF updated (v22 routed, DRC 0/0/0, case interferences 0)
    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
